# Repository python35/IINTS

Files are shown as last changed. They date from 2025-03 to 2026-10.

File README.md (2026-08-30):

# IINTS MK1

**Original first-generation open-source insulin pump research prototype**

> You are viewing the **`mk1` branch**. For the second-generation firmware,
> Calm Mode, UI simulator, controller PCB, and open KiCad design files, open the
> [`mk2` branch](https://github.com/python35/IINTS/tree/mk2).

<div align="center">
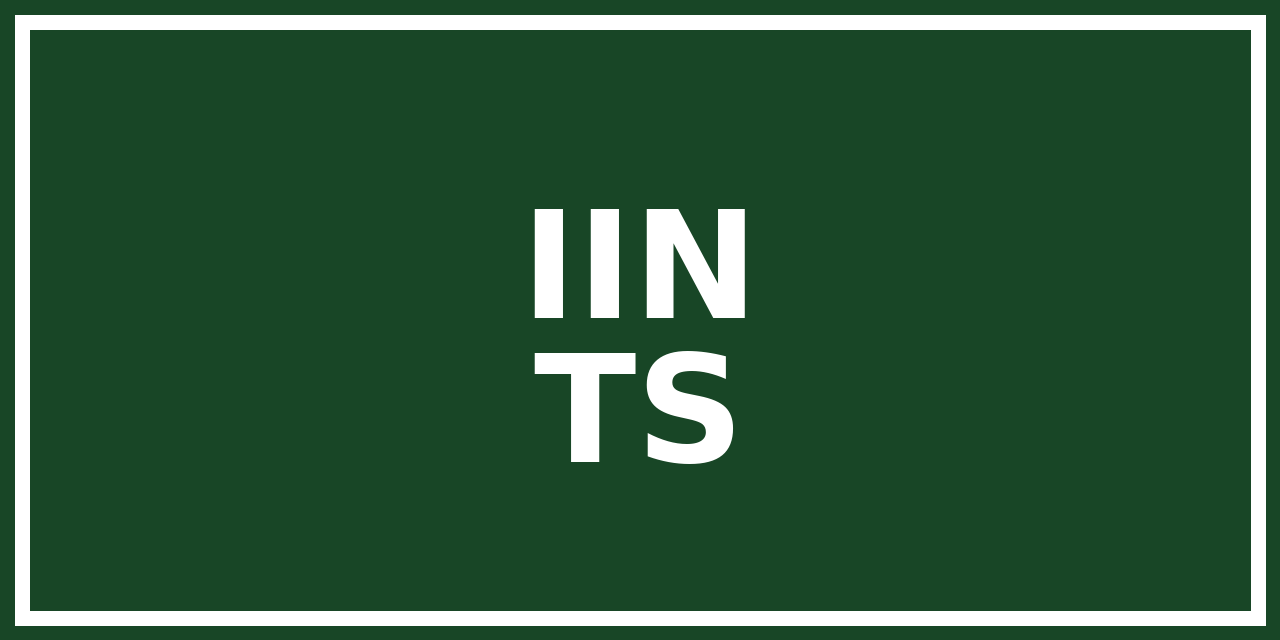
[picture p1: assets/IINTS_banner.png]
  
</div>

**IINTS MK1** (*Insuline Is Not The Solution*) is the original open-source educational insulin pump prototype built around the **Raspberry Pi Pico**.

The project started as an experiment to understand how insulin pumps work from an engineering perspective: how a motor can create precise linear movement, how that movement can be translated into fluid displacement, and how embedded software can control the complete mechanism.

The first generation of IINTS combines a **Raspberry Pi Pico**, a **stepper-driven syringe mechanism**, a display, physical controls, and a 3D-printed enclosure.

> **Important:** IINTS is an educational and research prototype.
> It is **not a medical device**, has not been clinically validated or certified, and must **not be used to administer insulin or any other medication to a person**.

## Project Branches

- **`mk1` branch:** The original pump firmware, assets, guide, and mechanical
  files documented on this page.
- **`mk2` branch:** The second-generation controller, firmware, Calm Mode,
  simulator, PCB sources, and dedicated MK2 documentation are available on
  [the MK2 branch](https://github.com/python35/IINTS/tree/mk2).

---

## About the Project

I started IINTS in **2024** after becoming curious about the technology behind the insulin pumps I had been using for most of my life.

Instead of treating the pump as a closed box, I wanted to understand what was happening inside it:

* How does a pump physically move a small amount of fluid?
* How can a stepper motor be controlled accurately?
* How do mechanical dimensions influence displacement?
* How can an embedded user interface control the mechanism?
* What engineering challenges appear when combining electronics, software and mechanics into a small device?

IINTS became my way of exploring those questions by building a pump mechanism from scratch.

The project is published as open source so that others interested in **embedded systems, electronics, programming, 3D printing and medical technology** can study and experiment with the concepts behind it.

---

## Project History

### Milestones

* **May 2024** – First working prototype using a Raspberry Pi Pico
* **July 2024** – Added a display and user interface
* **December 2024** – Introduced microstepping experiments to improve motor control and mechanical resolution
* **April 2025** – Awarded **Most Technically Complex Project** at Coolest Projects Belgium
* **May 2025** – Named **Student in the Spotlight** for the third time, this time for IINTS
* **July 2025** – Ranked among the top 7% of applicants from more than 120 countries for the CERN Solvay Student Camp
* **August 2025** – Presented IINTS at the CIONET Summer Festival
* **October 2025** – Presented the project at HackYeah in Kraków, Poland

---

## Hardware Overview

The first-generation IINTS prototype consists of several main subsystems:

### Controller

* **Raspberry Pi Pico**
* RP2040 microcontroller
* Firmware written in **MicroPython**

The Pico controls the motor, display and physical user inputs.

### Motor System

A small stepper motor drives a threaded linear mechanism.

Rotational movement from the motor is converted into linear movement, which pushes the syringe plunger forward.

The motor is controlled through a dedicated motor driver.

### User Interface

The prototype includes:

* Display-based interface
* Physical push buttons
* Motor control
* Basic device status information

### Mechanical System

The mechanical assembly consists of:

* Stepper motor
* Threaded spindle / linear actuator
* Syringe holder
* Plunger mechanism
* 3D-printed mounting components
* 3D-printed enclosure

---

## How the Pump Mechanism Works

The basic mechanical principle is relatively simple.

A stepper motor rotates a threaded spindle. The spindle converts the rotational movement of the motor into linear movement.

That linear movement pushes the plunger of a syringe.

Because the dimensions of the syringe, spindle pitch and motor movement are known, the theoretical fluid displacement per motor revolution or motor step can be estimated.

### Volume per Revolution

For a syringe with internal radius \(r\) and a spindle with pitch \(p\):

$$
V_{rev} = \pi r^2 p
$$

where:

* \(V_{rev}\) = theoretical displaced volume per spindle revolution
* \(r\) = internal radius of the syringe
* \(p\) = linear spindle travel per revolution

### Volume per Motor Step

If the motor requires \(N_{steps}\) controlled steps for one revolution:

$$
V_{step} = \frac{V_{rev}}{N_{steps}}
$$

This provides a theoretical relationship between motor movement and syringe displacement.

These equations describe the **mechanical principle only**. Real systems are affected by factors such as backlash, friction, syringe tolerances, motor accuracy, compliance and assembly tolerances.

The calculations in this repository must therefore **not be interpreted as validated medication-delivery accuracy**.

---

## Features

### Raspberry Pi Pico Control

The device is controlled by an RP2040-based Raspberry Pi Pico running MicroPython.

### Stepper Motor Control

A stepper motor provides controlled mechanical movement of the syringe plunger.

### Display Interface

A small display provides a graphical interface for interacting with the prototype.

### Physical Controls

Push buttons allow the user to navigate the interface and control the demonstrator.

### 3D-Printed Mechanism

The enclosure and several mechanical components can be produced using a standard FDM 3D printer.

### Open Source

The firmware, mechanical designs and documentation are publicly available so that the project can be studied, modified and improved.

---

## Project Images

<table align="center">
  <tr>
    <td align="center">
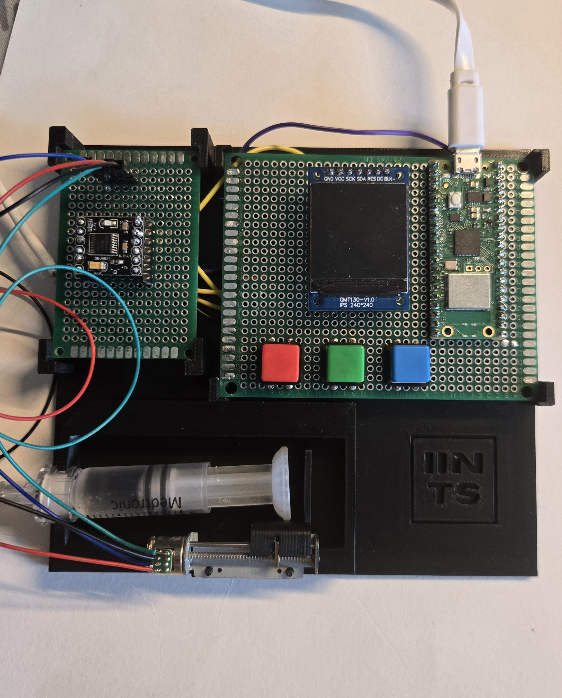
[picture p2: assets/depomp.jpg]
      
    </td>
  </tr>
  <tr>
    <td align="center">
      First-generation IINTS prototype
    </td>
  </tr>
</table>

---

## Hardware

The exact hardware used has changed during development, but the prototype is built around the following components.

### Electronics

* **Raspberry Pi Pico (RP2040)**
* **TFT / graphical display**
* **Stepper motor**
* **Stepper motor driver**
* **Physical push buttons**
* **USB or battery-based power supply**

### Mechanical Components

* Syringe-based linear mechanism
* Threaded spindle / actuator
* Motor mount
* Syringe mount
* Plunger interface
* 3D-printed enclosure

> Different revisions of the prototype may use different components or wiring.
> Check the firmware and hardware files in the repository for the configuration corresponding to a specific revision.

---

## 3D Printing

The available 3D-printable components can be found in the [`/stl`](https://github.com/python35/IINTS/tree/mk1/stl) directory.

### Suggested Starting Settings

These settings were used as a general starting point during prototyping:

* **Material:** PLA or PETG
* **Layer height:** 0.2 mm
* **Infill:** approximately 20%
* **Bed adhesion:** skirt or brim where necessary
* **Supports:** dependent on part orientation

These are prototype settings rather than strict manufacturing specifications.

---

## 3D Printing Timelapses

3D Print Timelapse 1

3D Print Timelapse 2

---

## Software

The firmware is written in **MicroPython** and runs directly on the Raspberry Pi Pico.

### MicroPython Version

The original prototype was developed using:

**MicroPython v1.23.0 – 2024-06-02**

for the Raspberry Pi Pico.

MicroPython firmware for the Raspberry Pi Pico is available at:

https://micropython.org/download/RPI_PICO/

### Check the Installed Version

Connect to the MicroPython REPL and run:

```python
import os
print(os.uname())
```

---

## Development Environment

The original firmware was primarily developed using **Thonny**.

Thonny can be downloaded from:

https://thonny.org/

### Raspberry Pi Pico Setup

1. Connect the Raspberry Pi Pico to your computer.
2. Open Thonny.
3. Select the Raspberry Pi Pico / MicroPython interpreter.
4. Install MicroPython on the Pico if necessary.
5. Copy the required project files to the Pico.
6. Run the firmware.

---

## Clone the Repository

```bash
git clone https://github.com/python35/IINTS.git
cd IINTS
```

You can also download the repository as a ZIP file directly from GitHub.

---

## Repository Structure

The repository contains the different parts of the first-generation IINTS project, including firmware, assets and mechanical files.

For example:

```text
IINTS/
├── assets/
│   └── project images and media
│
├── stl/
│   └── 3D-printable components
│
├── main.py
│   └── main MicroPython firmware
│
└── README.md
```

The exact structure may change as the repository evolves.

---

## What This Project Is

IINTS is intended as:

* an educational embedded-systems project
* an exploration of insulin-pump mechanics
* an open-source hardware experiment
* a way to study stepper motor control
* a project for learning MicroPython
* an example of combining electronics, software and 3D printing
* a platform for discussing transparency in medical technology

---

## What This Project Is Not

IINTS is **not**:

* a certified insulin pump
* a replacement for a commercial insulin pump
* clinically validated
* intended for treatment decisions
* intended for administering medication
* a source of medical dosing advice
* suitable for human use

The project demonstrates engineering concepts only.

---

## Contributing

Contributions are welcome.

If you want to experiment with the project:

1. Fork the repository.
2. Create your own branch.
3. Make and document your changes.
4. Submit a Pull Request.

Improvements to the firmware, documentation, electronics, mechanical design and simulation tools are all welcome.

Please keep the educational and non-clinical nature of the project clear when contributing.

---

## License

This repository is licensed under the **MIT License**.

The license allows the source code and project files to be used, modified and redistributed under the terms of the MIT License.

The MIT License does **not** imply that the hardware or software is safe, clinically validated, medically approved or suitable for use as a medical device.

---

## Safety Disclaimer

**IINTS is an experimental educational prototype.**

The hardware, firmware, mechanical components and calculations in this repository have **not been designed, tested, validated or certified for clinical use**.

Do not connect this prototype to a person and do not use it to administer insulin, medication or other substances.

Commercial insulin pumps are safety-critical medical devices that require extensive engineering controls, verification, validation, risk management, manufacturing controls and regulatory approval. This project does not provide those guarantees.

Use the repository only for **education, research and engineering experimentation**.

---

## Special Thanks

A special thank you to the **coaches of CoderDojo Genk and Hasselt** for their guidance and support throughout the development of IINTS.

Their feedback and mentorship helped turn an early experiment into a much larger engineering and educational project.

---

## Related Development

This repository documents the **original hardware-focused generation of IINTS**.

The project has since grown beyond the physical pump prototype into broader research and educational work around diabetes technology, simulation, algorithmic safety and transparent medical technology.

The original pump remains an important part of that story: it was the starting point for understanding what happens between a line of software and the physical movement of a medical device.

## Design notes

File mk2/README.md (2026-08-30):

# IINTS MK2

**Neuro-inclusive insulin pump simulator, open hardware study, and
electromechanical demonstrator**

[Back to the main IINTS repository](../README.md)

This README describes the **IINTS MK2 only**. The MK1 has different hardware,
wiring, firmware, and interaction patterns.

> [!CAUTION]
> **Research and education prototype only.** IINTS MK2 is not a certified
> medical device and must not be used to make treatment decisions or deliver
> insulin to a person. Test the mechanism disconnected from a person and use
> water or another harmless test liquid. The calculations and safety checks are
> demonstrations, not a substitute for validated pump firmware or clinical
> supervision.

<table>
  <tr>
    <td width="50%" align="center">
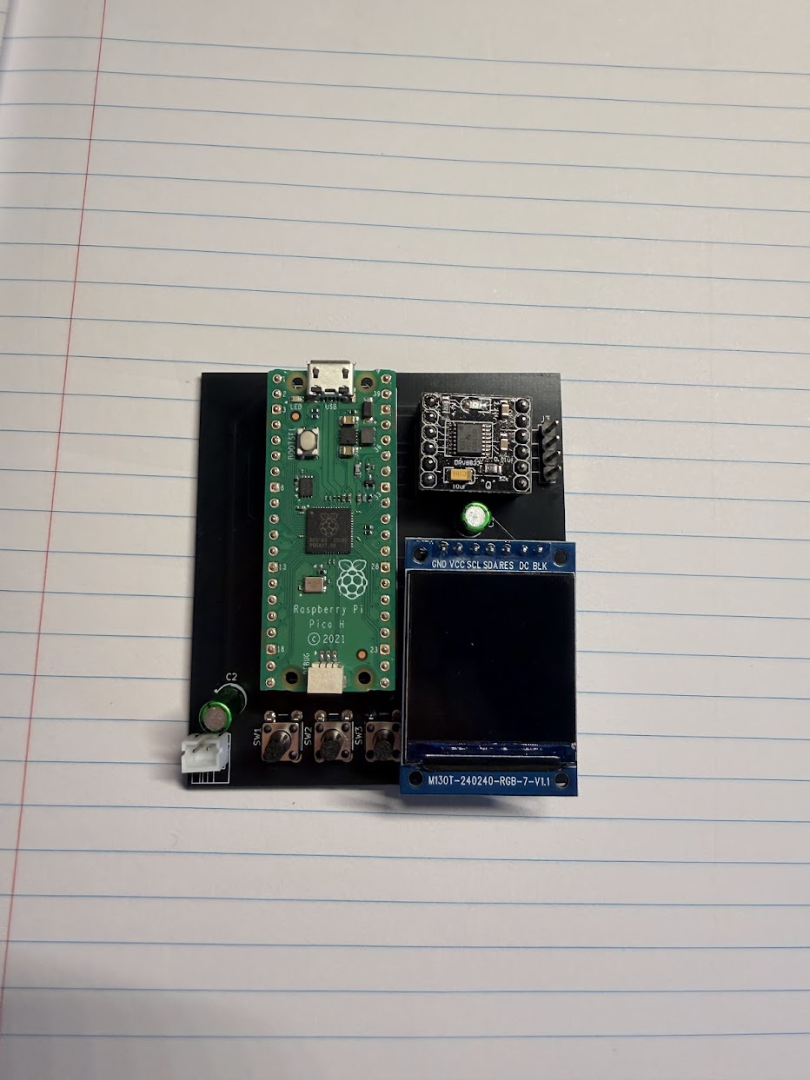
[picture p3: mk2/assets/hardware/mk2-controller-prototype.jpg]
Photograph of the IINTS MK2 controller PCB
      
    </td>
    <td width="50%" align="center">
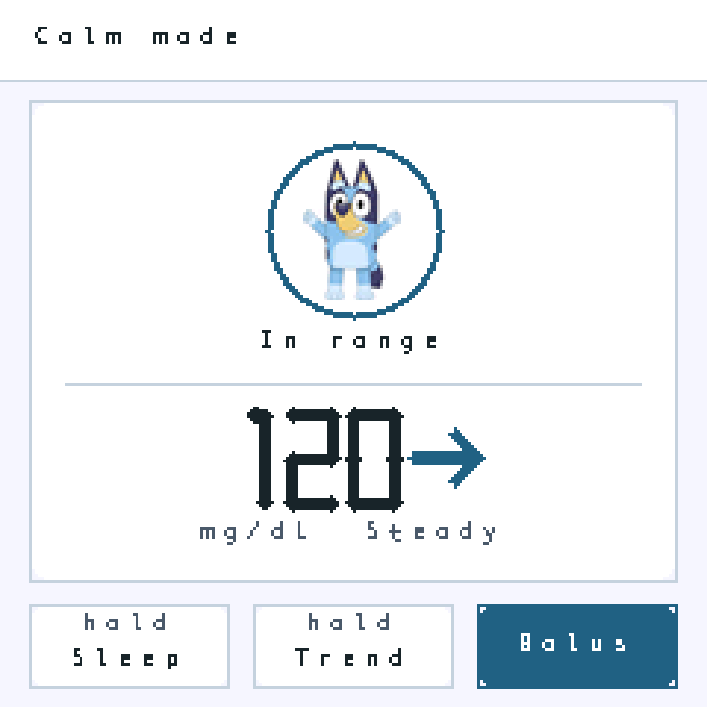
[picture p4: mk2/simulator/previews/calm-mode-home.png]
IINTS MK2 Calm Mode home screen
      
    </td>
  </tr>
  <tr>
    <td align="center"><strong>MK2 controller prototype</strong></td>
    <td align="center"><strong>Calm Mode interface</strong></td>
  </tr>
</table>

## Quick Links

| Area | Open files |
| --- | --- |
| Firmware source | [`firmware/pico_drv8833_correct_pins.py`](firmware/pico_drv8833_correct_pins.py) |
| Ready-to-upload Pico build | [`firmware/deploy/`](firmware/deploy/) |
| PCB V2 KiCad project | [`hardware/pcb-v2/`](hardware/pcb-v2/) |
| Desktop UI simulator | [`simulator/`](simulator/) |
| Complete UI overview | [`simulator/previews/current-ui-overview.png`](simulator/previews/current-ui-overview.png) |
| Calm Mode documentation | [`docs/NEURODIVERGENT_MODE.md`](docs/NEURODIVERGENT_MODE.md) |
| Simulator guide | [`docs/UI_SIMULATOR.md`](docs/UI_SIMULATOR.md) |
| MK2 project report | [`docs/IINTS-MK2.pdf`](docs/IINTS-MK2.pdf) |

## Overview

IINTS MK2 combines a Raspberry Pi Pico, a custom controller PCB/prototype
board, a 240 x 240 ST7789 IPS display, three physical buttons, a DRV8833 motor
driver, and a bipolar stepper motor. The prototype demonstrates:

- a virtual CGM value in `mg/dL`, refreshed once per minute;
- a visible rising, steady, or falling trend;
- standard and low-sensory **Calm Mode** interfaces;
- a guided carbohydrate and bolus flow;
- a separate adult confirmation before motor movement;
- educational IOB, COB, correction, and meal-dose calculations;
- a delivery animation and flashing onboard LED while the motor runs;
- glucose history, settings, manual rewind, screen locking, and power saving;
- a desktop simulator that previews the real firmware drawing functions;
- open MicroPython firmware, deployment files, documentation, assets, and
  editable KiCad design source.

The current firmware interface is in English.

## What Is New In MK2

Compared with the original concept, MK2 is built around a complete three-button
workflow and a full-colour IPS interface. Its main additions are the virtual CGM,
trend history, Calm Mode, visual meal portions, adult hand-off, runtime settings,
manual rewind, delivery feedback, and automatic sleep.

The desktop UI simulator is part of the MK2 workflow. It allows the 240 x 240
screens to be reviewed before anything is uploaded to the Pico.

## Project Status

| Part | Status |
| --- | --- |
| MicroPython firmware source | Published and used by the current prototype |
| Compiled Pico deployment package | Published in `firmware/deploy/` |
| Desktop UI simulator | Published and usable without a Pico |
| Calm Mode and buddy assets | Published with a separate artwork notice |
| MK2 controller photograph | Published in `assets/hardware/` |
| KiCad schematic source | Published as an editable V2 design draft |
| KiCad PCB layout | Early placeholder; not fabrication-ready |
| Gerbers, drill files, BOM, pick-and-place | Not released because the PCB design is unfinished |
| Medical or clinical validation | Not performed |

Publishing a source file does not make it a finished manufacturing release.
The exact PCB status is documented in the
[PCB V2 design notes](hardware/pcb-v2/README.md).

## User Interface

### Standard mode

Standard mode keeps the clinical data visible. The home screen shows the current
virtual sensor value, its direction, IOB, and COB. The bolus flow then asks for
carbohydrates, shows the calculated dose, and requires confirmation before the
motor can start.

### Calm Mode

Calm Mode reduces the number of decisions and visual elements shown at once:

- one primary task per screen;
- a fixed header, content area, and three-button footer;
- a cool-white background, dark text, and one muted-blue focus colour;
- written status labels in addition to colour and symbols;
- a small buddy image that supports, but never replaces, the glucose value;
- five predictable meal portions: `0`, `15`, `30`, `45`, and `60 g`;
- a dedicated Adult Check with a deliberate `1.4 s` hold;
- Calm Pause, which stops motor output and shows three short steps.

The UI is intended to reduce sensory and cognitive load. It has not undergone a
formal accessibility or medical usability certification.

<details>
<summary><strong>View the complete current 240 x 240 UI overview</strong></summary>

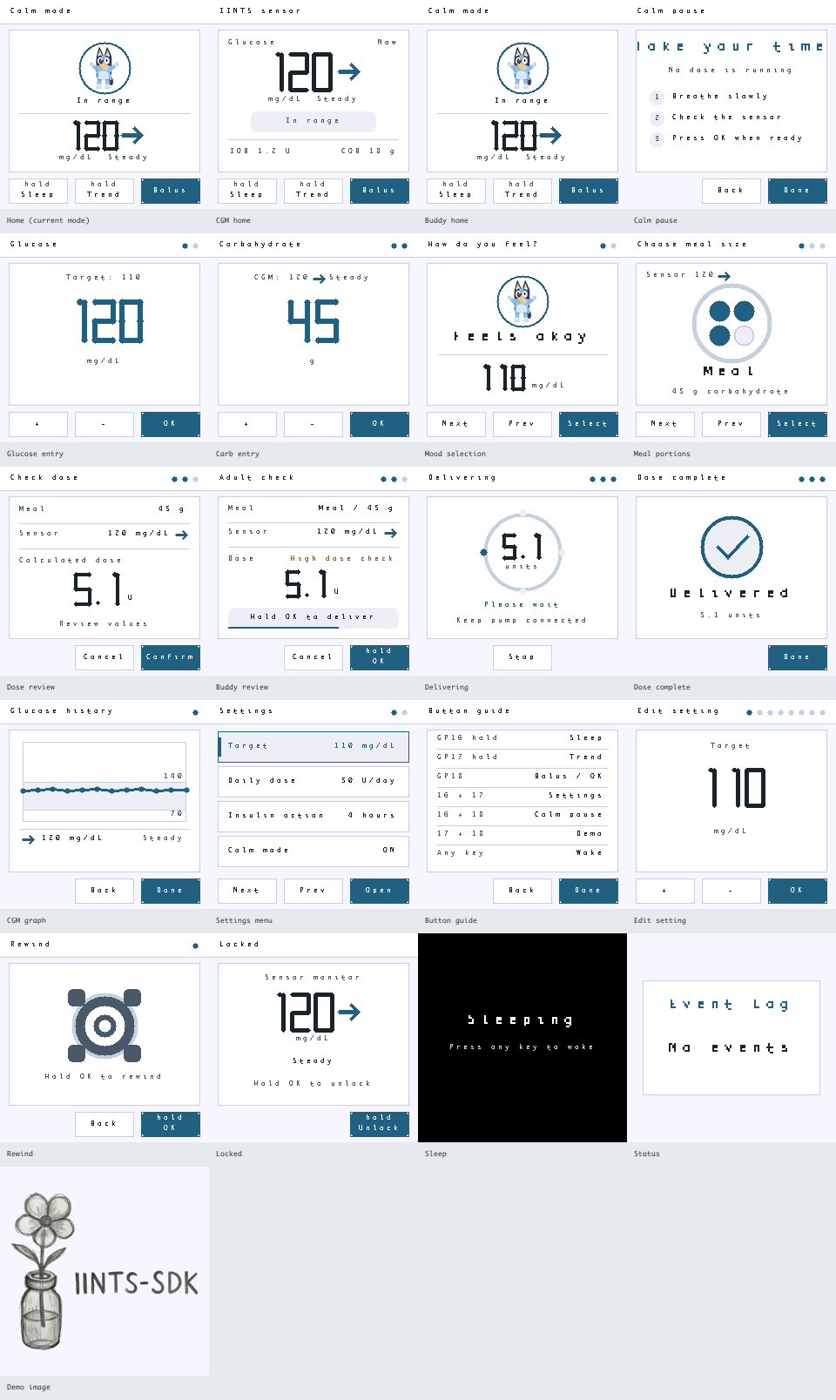
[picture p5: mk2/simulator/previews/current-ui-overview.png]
Complete IINTS MK2 interface overview


</details>

## Hardware

| Component | MK2 role |
| --- | --- |
| Raspberry Pi Pico or Pico W | Runs MicroPython, calculations, UI, and motor state machine |
| 240 x 240 ST7789 IPS display | Main interface over SPI1 |
| DRV8833 dual H-bridge | Drives the bipolar stepper motor |
| Bipolar stepper motor | Demonstrates plunger movement |
| Lead screw and test reservoir | Converts rotation into linear movement |
| Three active-low push buttons | Previous/down, next/up, and OK |
| External motor battery/supply | Powers `VM` on the motor driver |

The motor calculation currently assumes a 200-step motor, a `0.5 mm` lead-screw
pitch, and a `9.5 mm` reservoir inner diameter. Real hardware must be measured
and calibrated before its movement can be interpreted as a volume.

## Open PCB V2 Design

The complete supplied KiCad V2 source is available in
[`hardware/pcb-v2/`](hardware/pcb-v2/). Open
[`ai_pomp.kicad_pro`](hardware/pcb-v2/ai_pomp.kicad_pro) with **KiCad 9**.

The directory includes the project, root schematic, hierarchical schematic
sheets for USB-C, the display, controller pins, motor driver, and buttons, plus
the early PCB placement file. Temporary locks, autosaves, and backup archives
are deliberately excluded because Git provides the version history.

> [!WARNING]
> The supplied KiCad files are an early V2 design study. The PCB file still
> contains generic placeholder footprints and is not routed or ready to order.
> It does not yet match the photographed Pico-based controller one-to-one. Read
> the [PCB design notes](hardware/pcb-v2/README.md) before reusing it.

This distinction keeps the full design history public without presenting an
unfinished board as validated hardware.

## Wiring

The GPIO names below are the source of truth for the firmware. Physical pin
numbers refer to a standard 40-pin Raspberry Pi Pico/Pico W.

### Pico to DRV8833

| Pico GPIO | Physical pin | DRV8833 |
| --- | ---: | --- |
| `GP4` | 6 | `IN1` |
| `GP5` | 7 | `IN2` |
| `GP6` | 9 | `IN3` |
| `GP9` | 12 | `IN4` |
| `GP28` | 34 | `EEP` / enable |
| `3V3(OUT)` | 36 | Logic `VCC`, if present on the module |
| `GND` | 38 | `GND` |

### DRV8833 to motor

| DRV8833 | Motor |
| --- | --- |
| `OUT1` | Coil A+ |
| `OUT2` | Coil A- |
| `OUT3` | Coil B+ |
| `OUT4` | Coil B- |

If the motor only vibrates, verify the two coil pairs before changing the
firmware sequence.

### Display to Pico

| Display | Pico GPIO | Physical pin |
| --- | --- | ---: |
| `GND` | `GND` | Any Pico GND |
| `VCC` | `3V3(OUT)` | 36 |
| `SCK` | `GP10` | 14 |
| `SDA` / `MOSI` | `GP11` | 15 |
| `RES` | `GP12` | 16 |
| `DC` | `GP13` | 17 |
| `BLK` | `3V3(OUT)` | 36 |

`BLK` is connected directly to 3.3 V, so the current firmware cannot dim the
backlight with PWM.

### Buttons

| Button | Pico GPIO | Physical pin | Other side |
| --- | --- | ---: | --- |
| Button 1 | `GP16` | 21 | `GND` |
| Button 2 | `GP17` | 22 | `GND` |
| Button 3 | `GP18` | 24 | `GND` |

The firmware enables the Pico's internal pull-up resistors. A pressed button
therefore reads `LOW`.

### Power

- Battery positive goes to DRV8833 `VM`.
- Battery negative goes to the common ground.
- Pico GND, DRV8833 GND, battery negative, display GND, and button GND must be
  connected together.
- Do not power the motor from the Pico's 3.3 V output.
- On a standard Pico, physical pin **36** is `3V3(OUT)`. Physical pin **40** is
  `VBUS`, not 3.3 V. Verify the exact board and driver-module pinout before
  applying power.

See the [official Raspberry Pi Pico documentation](https://www.raspberrypi.com/documentation/microcontrollers/pico-series.html)
for the board pinout.

## Complete Control Legend

| Input | Normal action |
| --- | --- |
| `GP16` | Next, increase, or move upward |
| `GP17` | Previous, decrease, back, cancel, or stop delivery |
| `GP18` | Select, OK, confirm, or continue |

Values repeat automatically while `GP16` or `GP17` is held. Repeating becomes
faster after approximately `0.9 s` and faster again after `2.2 s`.

| Hold or combination | Action |
| --- | --- |
| Hold `GP16` for `2.5 s` on Home | Enter power-saving sleep |
| Hold `GP17` for `0.9 s` on Home | Open glucose history |
| Hold `GP18` during Adult Check | Confirm delivery after `1.4 s` |
| Hold `GP18` in Rewind | Run the motor backwards only while held |
| Hold `GP16 + GP17` for `0.7 s` | Open or close Settings |
| Hold `GP16 + GP18` for `0.7 s` in Calm Mode | Open Calm Pause |
| Hold `GP17 + GP18` for `0.7 s` | Show or close the project image/demo |
| Press any button while sleeping | Wake the display and driver |

The same legend is available on the device under `Settings > Button guide`.

## Guided Bolus Flow

With the default virtual CGM and Calm Mode enabled:

1. Home shows the current sensor value and trend.
2. Press `GP18` to start a bolus.
3. Select one of the five meal portions.
4. Review the meal, sensor value, trend, and calculated dose.
5. Continue to Adult Check.
6. An adult holds `GP18` for `1.4 s` to authorize motor movement.
7. During delivery, an hourglass-style animation is shown and the onboard Pico
   LED flashes.
8. Press `GP17` to stop delivery early.
9. A quiet checkmark confirms completion.

In Standard mode, carbohydrates can be changed in grams. Holding a value button
accelerates the adjustment.

## Settings

Open Settings by holding `GP16 + GP17` for `0.7 s`.

| Setting | Default | Range or action |
| --- | ---: | --- |
| Target | `110 mg/dL` | `80-180 mg/dL` |
| Daily dose (TDD) | `50 U/day` | `10-100 U/day` |
| Insulin action (DIA) | `4 h` | `2-8 h` |
| Calm Mode | On | On/off |
| CGM sensor simulation | On | On/off |
| Animations | On | On/off |
| Rewind | - | Hold `GP18` to reverse motor movement |
| Button guide | - | Opens the complete onboard legend |

Settings currently live in RAM only. Restarting the Pico restores the defaults
defined in `pico_drv8833_correct_pins.py`.

## Active Educational Model

The following calculations are active in the current bolus path.

### Patient factors

Using total daily dose `TDD`:

```text
ICR = 500 / TDD       grams per unit
ISF = 1800 / TDD      mg/dL per unit
```

At the default `TDD = 50 U/day`, this gives `ICR = 10 g/U` and
`ISF = 36 mg/dL/U`.

### Insulin on board

For each logged dose still inside the configured duration of insulin action:

```text
remaining IOB = dose * (1 - elapsed / DIA)^2
```

This is a simplified quadratic demonstration model. It must not be presented as
a validated patient-specific pharmacokinetic model.

### Carbohydrates on board

COB decreases linearly over `3 h` for standard portions and `6 h` for the
largest meal portion.

### Bolus calculation

```text
meal dose       = carbohydrates / ICR
correction dose = (current BG - target BG) / ISF
protected IOB   = max(0, IOB - COB / ICR)
bolus           = max(0, meal dose + correction dose - protected IOB)
```

The result is then limited by the educational guardrails below.

### Motor conversion

The current assumptions are:

```text
reservoir radius       = 4.75 mm
lead-screw pitch       = 0.5 mm/revolution
stepper resolution     = 200 steps/revolution
U-100 reference volume = 10 microlitres/unit
calculated output      = 3.544 units/revolution
calculated resolution  = 56.43 steps/unit
```

These values describe the software model, not a calibration certificate for the
physical prototype.

## Educational Guardrails

| Check | Current behaviour |
| --- | --- |
| Low-glucose lockout | A calculated bolus is blocked at or below `70 mg/dL` |
| Single-bolus limit | Requested dose is clamped to `15.0 U` |
| Rolling dose limit | Logged delivery since boot is limited to `2 x TDD` over 24 hours |
| Adult hand-off | Calm Mode requires a continuous `1.4 s` hold before delivery |
| Delivery cancel | `GP17` stops the motor and records only completed steps |
| Motor shutdown | All four driver inputs are set low after movement |

These safeguards are implemented for demonstration and have not been validated
to medical-device standards. The injection and carbohydrate logs are volatile;
they are lost when power is removed.

The source also contains experimental PID basal, predictive-low-glucose, and
sensor-noise helper functions. They are **not connected to the current main
delivery loop** and should not be described as active closed-loop control.

## Virtual CGM

The MK2 does not currently communicate with a physical glucose sensor. The
default demo cycles through this sequence once per minute:

```text
118, 124, 132, 145, 158, 151, 138, 126, 113, 101, 108, 116 mg/dL
```

The trend is rising for a change of at least `+5 mg/dL`, falling for a change of
at most `-5 mg/dL`, and steady otherwise. Up to 24 samples are kept in RAM for
the history graph.

## Locking And Power Saving

- Home locks after `30 s` without input while the virtual CGM is active.
- The display and driver enter sleep after `180 s` without input.
- Holding `GP16` for `2.5 s` enters sleep immediately.
- Sleep disables the motor, turns off the delivery LED, lowers the driver enable
  pin, sends the ST7789 sleep command, and uses Pico light sleep where available.
- Any button wakes the prototype.

Because `BLK` is wired directly to 3.3 V, actual backlight power depends on the
display module. For maximum battery saving, route `BLK` through a suitable GPIO
or transistor in a future hardware revision.

## Repository Layout

```text
mk2/
|-- README.md                         # This GitHub start page
|-- assets/
|   |-- branding/                     # IINTS logo and startup preview
|   |-- bluey/                        # Source, generated assets, and rights note
|   `-- hardware/                     # MK2 controller photograph
|-- docs/                             # Project report and focused guides
|-- firmware/
|   |-- pico_drv8833_correct_pins.py  # Canonical readable firmware
|   |-- st7789.py                     # Display driver
|   `-- deploy/                       # Ready-to-copy Pico filesystem
|-- hardware/
|   `-- pcb-v2/                       # Editable KiCad 9 V2 design source
|-- simulator/                        # Safe desktop UI simulator and previews
|-- tools/                            # Asset preparation and button tests
`-- requirements.txt                  # Desktop development dependencies
```

Only `happy_calm.raw`, `sad_calm.raw`, and `angry_calm.raw` are used by the
current buddy interface. Old food-image and startup-video experiments are not
part of the deployed MK2 package.

## Preview The UI

The simulator needs Python 3 and Tkinter, but no connected Pico:

```bash
cd mk2
python3 -m venv .venv
source .venv/bin/activate
python -m pip install -r requirements.txt
python simulator/ui_simulator.py
```

On macOS, double-click `simulator/Open UI Simulator.command`. The simulator can
preview individual screens, emulate all three buttons, auto-reload UI changes,
save screenshots, and export a complete contact sheet.

Generate a contact sheet from the command line with:

```bash
python simulator/ui_simulator.py \
  --contact-sheet simulator/previews/all-screens.png
```

The simulator replaces GPIO, SPI, timing, and motor access with desktop stubs.
It validates layout and interaction screens, not physical delivery behaviour.

See the [simulator guide](docs/UI_SIMULATOR.md) for the full workflow.

## Build The Pico Application

Install a current MicroPython build for the exact Pico model and confirm that a
REPL is available. Then create the development environment:

```bash
cd mk2
python3 -m venv .venv
source .venv/bin/activate
python -m pip install -r requirements.txt
```

Compile the large source file before copying it to the Pico:

```bash
mpy-cross \
  -o firmware/deploy/pico_app.mpy \
  firmware/pico_drv8833_correct_pins.py
```

The `mpy-cross` format must be compatible with the MicroPython firmware on the
Pico. An incompatible build raises `ValueError: incompatible .mpy file`. See
the [official MicroPython `.mpy` documentation](https://docs.micropython.org/en/latest/reference/mpyfiles.html).

The included deploy build is documented as tested with MicroPython 1.28.0.
Rebuild it whenever the Pico firmware or readable source changes.

## Deploy To A Pico

Back up the Pico filesystem first. The ready-to-copy directory contains:

```text
firmware/deploy/
|-- main.py
|-- pico_app.mpy
|-- st7789.py
|-- start.raw
|-- happy_calm.raw
|-- sad_calm.raw
`-- angry_calm.raw
```

With the development environment active and the Pico connected:

```bash
mpremote connect auto fs cp \
  firmware/deploy/main.py \
  firmware/deploy/pico_app.mpy \
  firmware/deploy/st7789.py \
  firmware/deploy/start.raw \
  firmware/deploy/happy_calm.raw \
  firmware/deploy/sad_calm.raw \
  firmware/deploy/angry_calm.raw :

mpremote connect auto reset
```

The deployment `main.py` imports only `pico_app.mpy`. This avoids compiling the
large readable firmware source on the Pico and reduces the chance of
`MemoryError`. The explanatory `firmware/deploy/README.md` is not needed on the
device.

The same files can be uploaded with Thonny. Place all seven runtime files in the
Pico filesystem root and restart the board.

## Troubleshooting

### `ImportError: no module named 'st7789'`

Upload `firmware/deploy/st7789.py` to the Pico root next to `pico_app.mpy`.

### `MemoryError`

- Use `firmware/deploy/pico_app.mpy` with the minimal deployment `main.py`.
- Remove the large `.py` application source from the Pico after compiling it.
- Remove obsolete video frames, food photos, and unused raw assets.
- Keep the three 64 x 64 buddy files streamed from flash; do not load a full
  image into RAM.

### `ValueError: incompatible .mpy file`

Recompile with an `mpy-cross` release that matches the MicroPython firmware on
the Pico.

### Buttons do not respond

- Confirm that each button connects its GPIO to common GND when pressed.
- Run `tools/test_buttons.py` or `tools/scan_buttons_safe.py` first.
- Check `GP16`, `GP17`, and `GP18`; the inputs are active low.
- Release all buttons before testing a two-button hold.

### The motor vibrates but does not rotate

Identify the two motor coils with a multimeter and connect each complete coil to
one DRV8833 output pair. Also verify `VM`, common ground, and `GP28` enable.

### Buddy images are missing

The UI falls back to a geometric face if an image cannot be opened. Confirm the
exact filenames in the Pico filesystem root:

```text
happy_calm.raw
sad_calm.raw
angry_calm.raw
```

## Suggested Test Order

1. Review every screen in `simulator/ui_simulator.py`.
2. Test the three buttons with the motor supply disconnected.
3. Confirm display colours, labels, sleep, wake, Settings, and button combos.
4. Test motor direction without a reservoir attached.
5. Calibrate mechanical travel with a ruler or dial indicator.
6. Test repeatability with water and a precision scale.
7. Record the firmware version, measured geometry, supply voltage, and results.

Do not proceed from bench testing to human use. A real insulin pump requires a
validated risk-management process, redundant fault detection, verified dosing,
biocompatible fluid paths, alarms, persistent records, cybersecurity controls,
and regulatory approval that this prototype does not provide.

## Current Limitations

- virtual CGM only; no Bluetooth or physical sensor connection;
- no active basal-delivery schedule or validated closed-loop controller;
- no non-volatile settings, dose history, or event log;
- no occlusion, reservoir, battery-voltage, current, or motor-position sensor;
- no redundant processor or independent motor cutoff;
- unfinished PCB V2 design with no released manufacturing package;
- no MK2-specific enclosure CAD in this directory;
- no formal IEC 62304, ISO 14971, IEC 62366, electrical-safety, or clinical
  validation.

These limitations are intentionally explicit so the MK2 can be presented
accurately as a research demonstrator.

## License And Artwork

The original source code, KiCad files, and project documentation are published
under the repository's [MIT License](../LICENSE).

The optional Bluey buddy artwork is third-party material and is **not** covered
by the MIT License. All rights to that artwork remain with the relevant rights
holders. IINTS is not affiliated with or endorsed by them. See the
[Bluey asset notice](assets/bluey/README.md) for details.

## Author

Developed by **Rune Bobbaers** as part of the **IINTS** research project.

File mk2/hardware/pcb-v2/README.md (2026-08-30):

# IINTS MK2 PCB V2

This directory contains the editable KiCad source files supplied for the IINTS
V2 electronics concept. Open `ai_pomp.kicad_pro` with **KiCad 9** to inspect or
continue the design.

> [!WARNING]
> **Design source, not a production release.** The current board file is an
> early placement placeholder. It has no finished board outline, routing,
> copper pours, verified netlist, fabrication outputs, or manufacturing
> validation. Do not order this board or connect it to a person on the basis of
> these files.

## Project Files

| File | Purpose |
| --- | --- |
| `ai_pomp.kicad_pro` | Main KiCad project settings |
| `ai_pomp.kicad_sch` | Root hierarchical schematic |
| `ai_pomp.kicad_pcb` | Early PCB placement concept |
| `USB-C.kicad_sch` | USB-C power-input draft |
| `untitled.kicad_sch` | Seven-pin display connector sheet |
| `Motor_Driver.kicad_sch` | Motor-driver draft sheet |
| `Pinnen.kicad_sch` | Controller-pin/header draft sheet |
| `Schermpje.kicad_sch` | Additional interface draft sheet |
| `1e-knopje.kicad_sch` | Button 1 draft |
| `2e-knopje.kicad_sch` | Button 2 draft |
| `3e-knopje.kicad_sch` | Button 3 draft |

KiCad lock files, personal preferences, autosaves, and backup archives are
deliberately excluded. Git already provides version history for the published
source files.

## Known Differences From The Current MK2 Prototype

The active MK2 firmware and photographed controller use a Raspberry Pi Pico,
three buttons, a DRV8833 module, and a 240 x 240 ST7789 display. The supplied
KiCad draft predates that final wiring choice:

- `Pinnen.kicad_sch` describes a generic 2 x 20 controller header rather than
  the Pico's 40 castellated pins;
- `ai_pomp.kicad_pcb` contains placeholder footprints, including a compute
  module and a generic SPI display;
- the PCB file does not yet contain a complete schematic-derived netlist,
  tracks, vias, mounting holes, or a closed `Edge.Cuts` outline;
- the three separate button sheets are retained as source material but are not
  all linked into the current root hierarchy.

The files are published so the design history is open and can be improved, not
to suggest that this revision is fabrication-ready.

## Firmware GPIO Target

A future PCB revision should be checked against the canonical firmware mapping:

| Function | Pico GPIO |
| --- | --- |
| DRV8833 IN1, IN2, IN3, IN4 | `GP4`, `GP5`, `GP6`, `GP9` |
| DRV8833 enable | `GP28` |
| ST7789 SCK, MOSI, RES, DC | `GP10`, `GP11`, `GP12`, `GP13` |
| Buttons 1, 2, 3 | `GP16`, `GP17`, `GP18` to GND |

See the parent [MK2 README](../../README.md) for the complete wiring and power
notes.

## Before Fabrication

At minimum, a new hardware revision needs:

1. Pico/Pico W symbols and footprints that match the chosen board revision.
2. A complete schematic-to-PCB netlist matching the firmware GPIO table.
3. Verified USB-C power circuitry, supply limits, grounding, decoupling, motor
   current, reverse-polarity protection, and battery protection.
4. A finished board outline, mounting holes, connector clearances, routed
   copper, power planes, and readable silkscreen.
5. Clean KiCad ERC and DRC reports reviewed by a qualified electronics engineer.
6. Bench validation with current-limited power and the motor/load disconnected.
7. Gerber, drill, BOM, and pick-and-place exports generated only from the
   reviewed release commit.

This remains an educational electronics prototype and is not a medical-device
hardware design.

## License

These design sources are distributed with the repository under the terms in
the root [`LICENSE`](../../../LICENSE). Third-party symbols, footprints, and
component documentation retain their own applicable terms.

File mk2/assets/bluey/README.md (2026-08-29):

# Bluey Assets

These images are retained as part of the MK.2 Calm Mode prototype at the
project author's request. The `source` directory contains the supplied images;
the `generated` directory contains the 64x64 RGB565 versions used by the Pico.

Bluey is a third-party character. These character images are not covered by
the repository's MIT license, and all rights remain with their respective
rights holders. This research project is not affiliated with or endorsed by
those rights holders.

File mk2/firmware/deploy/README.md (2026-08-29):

# Pico Deploy Folder

Copy the runtime files in this directory to the root of the Pico filesystem;
this `README.md` itself is not required there. The included `pico_app.mpy` was
compiled from `../pico_drv8833_correct_pins.py` and tested with MicroPython
1.28.0.

Do not test motor delivery with insulin connected. This build is a research
prototype and has not been clinically validated.

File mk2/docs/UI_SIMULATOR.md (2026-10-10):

# IINTS UI Simulator

The simulator previews the real drawing functions from
`../firmware/pico_drv8833_correct_pins.py` without connecting to the Pico.

## Requirements

- **Windows**: Python 3.10+ (Tkinter is included with standard Python installations) and Pillow (`pip install pillow`).
- **Linux / WSL (Ubuntu/Debian)**: Tkinter is packaged separately and must be installed via `apt`:
  ```bash
  sudo apt update
  sudo apt install -y python3-tk python3-pil python3-pil.imagetk
  ```
  *(Note: Running GUI applications inside WSL also requires WSLg or an active X11 server).*

## Start

Double-click `simulator/Open UI Simulator.command`, or run:

```bash
cd mk2/simulator
python3 ui_simulator.py
```

On Windows (Command Prompt / PowerShell):

```powershell
cd mk2\simulator
python ui_simulator.py
```

## Workflow

1. Select a screen in the left column.
2. Change glucose, trend, carbs, dose, portion, or mode on the right.
3. Use the GP16, GP17, and GP18 buttons below the display, or keys `1`, `2`, `3`.
4. Use Quick access for Settings, Calm Pause, Trend, and the demo image.
5. Keep Auto-reload enabled while editing the firmware source.
6. Use Screenshot for the current 240x240 screen or Export all for a contact sheet.
7. Open **UI Builder** to design a separate screen by adding and arranging text,
   rectangles, circles, and lines on a 240x240 canvas.

## UI Builder

The builder opens from the simulator and starts with an editable example screen.
Manage screens with Add, Copy, Delete, and the screen selector. Select an element
from the Layers list or click it on the canvas, then drag it or edit its position,
size, text, and color in Properties. Use the layer controls to change draw order.
Projects containing multiple screens are saved as `.iintsui` JSON files and can
be reopened later. Screen PNG exports the active screen; Contact sheet exports
all screens together.

Export firmware creates a standalone MicroPython module with a `draw_<screen>(fb)`
function for each screen, plus `draw_custom_ui(fb)` as an alias for the first
screen. Each function draws onto an existing 240x240
`framebuf.FrameBuffer`; call it from the firmware and then call the firmware's
`flush()` to show it. The generated module does not initialize the display or
alter pump behavior. Firmware text uses the built-in 8x8 framebuffer font, so
it must contain ASCII characters. Always review exported UI code and test it on
the simulator before deploying it to pump hardware.

The screen list includes all 21 standard, Calm Mode, confirmation, maintenance,
sleep, and help views. Auto-reload watches the firmware source; restart the
simulator after changing `ui_simulator.py` itself.

The simulator uses fake GPIO, SPI, motor, and display modules. It cannot deliver
a dose or move the physical motor.

## Command-line contact sheet

```bash
python3 ui_simulator.py --contact-sheet previews/all_screens.png
```

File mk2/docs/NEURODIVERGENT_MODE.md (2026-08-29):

# IINTS-AF Calm Mode

Calm Mode is the neurodivergent-friendly interface for the Pico pump prototype.
It keeps the medical calculation unchanged while reducing visual and cognitive
load during normal monitoring and the guided bolus flow.

## Prototype Features

- One decision per screen with a fixed header, content area, and three button zones.
- Soft cool-white, grey, and muted-blue surfaces with dark readable text.
- Status is always written in words; colour is never the only signal.
- A small buddy image supports the reading without replacing the glucose value.
- Meal size uses four visible portions plus the exact carbohydrate amount.
- Delivery requires a separate adult review and a deliberate hold on `OK`.
- Calm Pause stops motor output and presents three short, predictable steps.
- Animations can be disabled in Settings without changing the calculations.

## Complete Pico Control Guide

- `GP16`: increase a value or move to the next choice.
- `GP17`: decrease a value, move to the previous choice, cancel, or stop delivery.
- `GP18`: select, confirm, or continue.
- Hold `GP16` on Home for 2.5 seconds: enter deep sleep.
- Hold `GP17` on Home for 0.9 seconds: open glucose history.
- Hold `GP18` on Adult Check: confirm delivery.
- Hold `GP18` in Rewind: run the motor backwards while held.
- Hold `GP16 + GP17` for 0.7 seconds: open or close Settings.
- Hold `GP16 + GP18` for 0.7 seconds in Calm Mode: open Calm Pause.
- Hold `GP17 + GP18` for 0.7 seconds: open or close the project demo image.
- Press any button while sleeping: wake the display.

The same guide is available on the pump under `Settings > Button guide`.

## Safety Note

This is a research prototype, not a certified medical device. UI and motor tests
should be performed with insulin disconnected and under qualified supervision.

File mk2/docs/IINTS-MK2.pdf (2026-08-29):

## An Educational Prototype of an Artificial Pancreas for Neurodivergent Learning

Bobbaers Rune

June 14, 2026

## Abstract

This project presents an educational prototype of an artificial pancreas, or insulin pump, developed within the IINTS vision of accessible science education. The device is not designed or certified for insulin administration in humans. Instead, it is a safe physical and digital model that demonstrates how complex diabetes-care technologies work. Internally, the prototype uses scientifically grounded computational models, including bi-exponential pharmacokinetic simulation, hydraulic volume calculations, PID closed-loop control, and state-feedback safety logic. Its educational purpose is twofold: to show that advanced medical algorithms can run on low-cost microcontrollers, and to provide a low-sensory interface that helps neurodivergent children understand Type 1 Diabetes in a safe simulation environment.

## 1 The History and Educational Vision of IINTS

Before discussing the technical design, it is important to define the context in which this prototype was created. The project was developed under the IINTS initiative. IINTS was not founded to compete with medical-device manufacturers, nor to produce illegal or unregulated medical devices. Its purpose is education, awareness, and scientific accessibility.

The pumps developed within IINTS are educational models. They are safe physical and digital prototypes designed to help patients, classmates, teachers, and medical students understand the technology behind diabetes care. By reconstructing a life-saving but often poorly understood device, the project demystifies the science of insulin pumps, artificial pancreas systems, and closed-loop control.

This particular prototype focuses on a group that is often overlooked in diabetes education: neurodivergent children. Instead of presenting diabetes technology only through abstract numbers and clinical terminology, the model uses visual, low-sensory interaction to make invisible biological processes more understandable.

## 2 Introduction

Type 1 Diabetes (T1D) is a chronic autoimmune condition in which the pancreas produces little or no insulin [1]. As a result, patients must learn how blood glucose, carbohydrates, insulin, physical activity, and timing interact. For children, this is already difficult; for neurodivergent children, the learning process can be made harder by cognitive overload, sensory stress, and interfaces that rely heavily on abstract numerical information.

Modern insulin pumps, continuous glucose monitors, and automated insulin-delivery systems are powerful technologies in diabetes care [2], but they are often experienced as closed, clinical, and difficult to understand. This can create distance between the user and the science that affects their daily life. The educational problem addressed by this project is therefore not only technical, but also pedagogical: how can complex diabetes technology be made visible, safe, and understandable?

This project proposes a low-sensory, open-source educational artificial pancreas prototype built around the Raspberry Pi Pico microcontroller. The prototype does not deliver insulin to humans. Instead, it simulates insulin delivery, glucose trends, and safety decisions in a controlled learning environment. Its purpose is to show that an affordable embedded system can combine realistic actuator mathematics, pharmacokinetic reasoning, and neurodivergent-friendly human–computer interaction.

## 3 Hardware Architecture

The educational prototype, named IINTS MK2, integrates a small set of low-cost embedded components selected for accessibility, reproducibility, and computational sufficiency. The central controller is a Raspberry Pi Pico based on the RP2040 microcontroller [18]. This platform is compact, inexpensive, widely documented, and powerful enough to run the required medical calculations in MicroPython while also controlling the display, buttons, and motor driver.

Motor actuation is handled through a DRV8833 motor driver [19], which provides bidirectional control of the pump actuator while isolating the microcontroller from the higher current requirements of the motor. Visual feedback is provided through an ST7789 TFT LCD screen [20]. This display allows the prototype to present both numerical information and simplified visual representations for the low-sensory interface mode. Together, these components create a physically realistic embedded platform for demonstrating artificial pancreas control logic without clinical use.

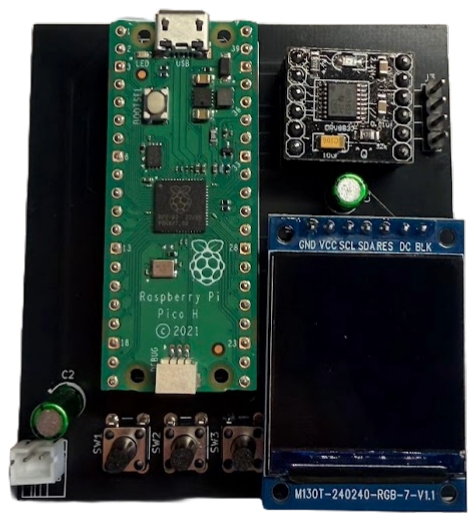
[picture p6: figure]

Figure 1. Physical IINTS MK2 educational artificial pancreas prototype. The photograph shows the compact IINTS MK2 pump model used to demonstrate actuator control, display feedback, and low-sensory interaction in a safe learning context.

## 4 Software Architecture

Medical software must remain responsive at all times. A pump interface should not freeze while the device waits for a sensor update, redraws a screen, or calculates a bolus. For this reason, the prototype software is structured as a non-blocking state machine in MicroPython. Instead of using long sleep() delays, the program compares timestamps using utime.ticks ms() and utime.ticks diff().

This architecture allows the pump to update the display, respond to buttons, process simulated CGM values, and evaluate safety formulas concurrently within the main loop. Listing 1 shows the timer-based structure used for real-time CGM simulation.

Listing 1: Non-blocking state machine for real-time CGM simulation

# Listing 1: Non-blocking state machine for real-time CGM simulation def update_cgm_sensor(force=False):

global huidige_bg, cgm_index, cgm_last_update_ms
now = utime.ticks_ms() # Get current time in milliseconds
elapsed_ms = utime.ticks_diff(now, cgm_last_update_ms)

# Update only if 60,000 ms (1 minute) have passed, without blocking the CPU if force or elapsed_ms >= CGM_UPDATE_MS:

steps = max(1, elapsed_ms // CGM_UPDATE_MS)
cgm_index = (cgm_index + steps) % len(CGM_PATTERN)
cgm_last_update_ms = now
huidige_bg = CGM_PATTERN[cgm_index]
return True

return False

As seen in Listing 1, the simulated sensor update is event-driven rather than delay-driven. This ensures that the processor remains available for interface updates and safety checks during every cycle of the program.

## 5 Biomechanics and Fluid Dynamics of the Actuator

Although the prototype is educational and not intended for human insulin delivery, realistic actuator mathematics are essential for demonstrating how real pumps calculate micro-doses. The stepper motor therefore imitates the fluid dynamics of a syringe-based pump using principles from hydraulics and cylindrical geometry.

### 5.1 Hydraulic Transmission: Pascal’s Principle

Insulin, as an aqueous solution, can be treated as practically incompressible in a first-order educational approximation. In the idealised model used here, the expelled volume is assumed to equal the mechanical reduction in reservoir volume. In real infusion systems, this relationship can be affected by compliance in the reservoir and tubing, backlash in the lead screw, trapped air, friction, pressure losses, and missed motor steps. The actuator in this project consists of a bipolar stepper motor connected to a lead screw that compresses a syringe-like reservoir.

### 5.2 Mathematical Volume and Dose Calculation

The conversion from GPIO signal to insulin-unit equivalent is modelled with the following assumptions. The dose values assume a 200-step motor; if an 18◦ per step micro linear stepper is used instead, the motor has only 20 steps per revolution and the per-step dose becomes ten times larger.

- Stepper motor assumption: Nsteps = 200 steps per revolution, corresponding to 1.8
- per
step.
- Lead screw pitch: p = 0.5 mm of linear displacement per revolution.
- Reservoir geometry: internal diameter 9.5 mm, giving r = 4.75 mm.

The volume conversion is:

Vrev = πr²

p = π · (4.75 mm)²

- 0.5 mm ≈ 35.44 mm³ = 35.44 µL,

Vstep =

Vrev

Nsteps

=

35.44 µL
200

≈ 0.177 µL/step.

For U-100 insulin, 1 unit = 10 µL. The insulin-unit conversion is therefore:

Drev =

35.44 µL
10 µL/unit

= 3.544 units,

Dstep =

0.177 µL/step
10 µL/unit

≈ 0.0177 units/step,

Steps per unit = | 1
| 0.0177

≈ 56.4 steps/unit.

Thus, the educational chain is GPIO signal → motor step → linear displacement → reservoir volume → insulin-unit equivalent. With a 20-step motor, the equivalent value would be approximately 0.177 units/step, ten times coarser than the 200-step assumption.

## 6 Pharmacokinetics: Bi-Exponential IOB Decay Model

A key learning objective of the model is the concept of active insulin, commonly referred to as Insulin On Board (IOB). In real diabetes care, tracking IOB is essential for preventing insulin stacking and the resulting risk of hypoglycaemia. Early insulin pumps often used simplified linear decay models, which assume that insulin activity disappears at a constant rate over time.

### 6.1 The Two-Compartment Bi-Exponential Model

In real pharmacokinetics, the absorption and clearance of subcutaneously administered insulin follow a complex two-compartment process: insulin first moves from subcutaneous tissue into the bloodstream and is then eliminated from circulation. To model this more realistically, the IINTS MK2 algorithm uses a bi-exponential approximation rather than a simplified quadratic curve. This approach is consistent with compartment-based modelling principles used in artificial pancreas research [5, 6].

The simulated active-insulin response is described as:

IOB(t) = Dose ·

ka
ka − ke
e

−ket − e

−kat

, | (1)

where ka is the absorption constant and ke is the elimination constant. The difference between these two exponential terms produces the characteristic rapid rise and long physiological tail of rapid-acting insulin.

In the MicroPython implementation, these exponential terms are calculated with the microcontroller’s mathematical library using math.exp. This allows the educational prototype to show that even a low-cost microcontroller can execute advanced pharmacokinetic calculations. For safety and clarity, the model is used for simulation and education only; it is not intended to determine real patient dosing.

Listing 2: Bi-exponential active-insulin calculation

def calculate_iob_biexponential(dose, elapsed_min, ka, ke): t = elapsed_min / 60.0 # minutes to hours
if t <= 0 or abs(ka - ke) < 0.0001:
return 0.0

activity = dose * (ka / (ka - ke)) * ( math.exp(-ke * t) - math.exp(-ka * t) )
return max(0.0, activity)

Listing 2 demonstrates how the mathematical model is translated into compact embedded code. By using exponentials directly, the IINTS MK2 can visualise the pharmacokinetic tail of insulin more faithfully than a straight-line decay model.

## 7 Control Theory: PID Controller for Closed-Loop Automation

A complete artificial pancreas does more than respond to manual bolus requests. It must continuously adjust basal insulin delivery based on the current glucose value and the simulated Continuous Glucose Monitor (CGM) trendline. In the IINTS MK2, this is demonstrated through a full PID controller, a classical feedback-control structure widely used in automation and closed-loop medical-device research [6, 8].

### 7.1 Proportional, Integral, Derivative Control

The controller calculates the error e(t) between the current blood glucose value and the target value once per simulated minute. This error is then weighted through three gains:

- Proportional (P): the current absolute deviation from the glucose target.
- Integral (I): the accumulated historical deviation, with windup restrictions to prevent excessive correction.
- Derivative (D): the rate of change of the glucose trendline, indicating whether glucose is rising or falling.

The resulting temporary basal adjustment is calculated as:

TempBasal(t) = Kp · e(t) + Ki

·

Z
e(t) dt + Kd ·

de(t)
dt . | (2)

This algorithm forms the educational core of closed-loop automation. It shows how a system can act before a glucose value becomes dangerously high or low, because the derivative term responds to the direction and speed of the trendline rather than only the current value. In the IINTS MK2, the PID output is limited by safety boundaries so that the demonstration remains bounded and interpretable.

## 8 Pharmacodynamics: Carbohydrate Absorption and Safety Algorithm

To calculate safe bolus behaviour in the simulation, the pump must also estimate how much glucose is still being absorbed from the digestive system. This quantity is referred to as Carbs On Board (COB). The algorithm integrates all meals recorded in the carb log over a medically standardised digestion time of 3 hours, or 180 minutes, for a mixed meal. A linear absorption model is applied:

COB(t) = Carbohydrates ·

1 −

telapsed

180 min
. | (3)

### 8.1 State Feedback and Conditional IOB Deduction

To demonstrate how artificial pancreas systems avoid overcompensation and integral windup, the software uses state feedback. The model shows how safety is built into meal-related dosing through a deductible-IOB limit:

Deductible IOB = max
0,IOB −

COB

ICR
, | (4)

where ICR is the insulin-to-carbohydrate ratio. This rule teaches users that active insulin is usually subtracted from a correction, except when that insulin is still needed to cover recently eaten carbohydrates. Only insulin that is effectively unassigned is deducted from the correction bolus. The final simulated dose is calculated as:

Total Dose = CarbBolus + CorrectionBolus − Deductible IOB. | (5)

Listing 3 shows how this safety concept is translated into MicroPython code.

Listing 3: The Deductible IOB safety algorithm

# Listing 3: The Deductible IOB Safety Algorithm

# We subtract active insulin (IOB) from the bolus, BUT we protect the insulin # that is reserved for digesting the stomach contents (COB).

# This prevents dangerous under-dosing (hyperglycemia) after a meal. cob_insulin_needed = cob / ICR

deductible_iob = max(0.0, iob - cob_insulin_needed)

# Calculate the final safe dose

berekende_dosis = carb_bolus + correction_bolus - deductible_iob # Ensure the pump never reverses or administers a negative dose totale_dosis = max(0.0, berekende_dosis)

As seen in Listing 3, the built-in max() function of MicroPython establishes a hard lower limit on deducted insulin and final dose output. As an educational demonstration, this formula links abstract control theory to an understandable safety concept: insulin can only be subtracted when it is not still needed for active carbohydrates.

## 9 Scientific Edge Cases and Advanced Logic

During development of the IINTS MK2 artificial pancreas simulation, several advanced clinical edge cases were identified and translated into mathematical logic. These cases are not included to enable real patient treatment, but to demonstrate that robust diabetes technology must respond to more than a single glucose value. Meals, sensor delay, circadian rhythm, and physical activity all change the meaning of the same numerical blood-glucose reading.

### 9.1 The “Pizza” Dual-Wave Bolus: Gastric Emptying

High-fat and high-protein meals can delay gastric emptying and extend postprandial glucose absorption, which is why real pump therapy often considers extended or dual-wave bolus strategies for meals such as pizza [9, 10]. In the Tamagotchi mode, selecting the “Pizza” portion automatically triggers a DUAL WAVE ACTIVE state. Mathematically, this changes the carbohydrate absorption window from the standard 3 hours to 6 hours:

Tabs =

(
180 min, standard meal,
360 min, dual-wave pizza mode.

(6)

This prevents the educational algorithm from modelling all carbohydrates as if they entered the bloodstream immediately. In practical terms, it teaches the user why a high-fat meal may cause a late hyperglycaemic rise even when the early glucose response appears safe.

### 9.2 Sensor Lag and Derivative Control

Continuous Glucose Monitors (CGMs) measure glucose in interstitial fluid rather than directly in capillary blood. This creates a physiological delay, often discussed in the range of several minutes, between the true blood-glucose trend and the sensor-reported value [11]. To demonstrate this limitation, the IINTS MK2 PID controller gives explicit educational importance to the derivative term, which estimates the direction and speed of glucose change.

The simplified prediction logic can be expressed as:

BGpredicted = BGCGM + τ ·

dBG
dt , | (7)

where τ represents an assumed sensor-lag horizon. This allows the simulation to show that the system should not only ask “What is the glucose now?”, but also “Where is the glucose going?”

### 9.3 Circadian Rhythm and the Dawn Phenomenon

Insulin sensitivity fluctuates over a 24-hour cycle because of hormonal rhythms, including early-morning counterregulatory hormones such as cortisol. The resulting dawn phenomenon can increase insulin needs in the early morning [12]. To demonstrate this, the code includes a get circadian isf() function that dynamically lowers the insulin sensitivity factor (ISF) between 04:00 and 08:00:

ISFeffective(t) = (
αdawn · ISFbase, 04:00 ≤ t < 08:00,
ISFbase, | otherwise,
0 < αdawn < 1. | (8)

Because correction insulin is inversely related to ISF, lowering the simulated ISF makes the model intervene more strongly against early-morning hyperglycaemia. This is presented as an educational demonstration of circadian physiology, not as a patient-specific dose rule.

### 9.4 Activity Mode and Physical Exercise

Physical activity can substantially increase insulin sensitivity and raise the risk of exercise-related hypoglycaemia in people with Type 1 Diabetes [13]. The IINTS MK2 therefore includes an ACTIVITY MODE. When enabled, the algorithm immediately raises the safe target glucose value and reduces PID aggressiveness:

T ARGETactivity = T ARGETbase + ∆activity, | Kactivity
p,i,d | = γ · Kbase
p,i,d , | 0 < γ < 1. | (9)

This teaches that safe closed-loop control is context-dependent: during exercise, a glucose value that would normally justify correction may instead require caution, basal reduction, or a higher temporary target.

## 10 Qualitative Validation & Expected Outcomes

Rather than conducting a quantitative clinical test, which falls outside the scope of an educational prototype, the UX design of the IINTS MK2 was qualitatively validated through empirical observations. These insights are directly informed by the author’s personal field experience as a youth camp counsellor (“moni”) at camps for neurodivergent children, including children with Autism Spectrum Disorder (ASD) and ADHD.

During these camps, medical actions—such as operating a complex insulin pump—were observed to cause acute overstimulation, frustration, and loss of autonomy in some children. Based on this practical field experience, the expected outcomes of the IINTS “Tamagotchi” interface are as follows:

- Reduction of cognitive overload: By replacing abstract numbers with a familiar Blueyinspired interface and photographs of meals, the task-initiation threshold for the child is expected to decrease substantially. A child may recognise “Pizza” faster than “60 g carbohydrates,” reducing uncertainty and performance anxiety.
- Increased medical sovereignty: In camp settings, children often hand over pump operation entirely to adults because they fear making mistakes with numerical inputs. The guided autonomous workflow allows the child to take the first step independently, strengthening ownership over their own body and care process.
- Prevention of alarm fatigue: Slow visual animations during simulated delivery replace shrill beeps, flashing warnings, and harsh alarm signals. This supports predictable and calm sensory processing, helping to prevent stress-related meltdowns at demanding moments such as mealtimes.

## 11 Cognitive Accessibility: Neurological and Visual Design

The most profound innovation of this educational prototype lies in the field of human–computer interaction (HCI) and psychology. Conventional medical devices are typically engineered by adults for clinical professionals, resulting in cold, number-heavy interfaces. For young children, and particularly neurodivergent users such as those with Autism Spectrum Disorder, ADHD, or dyslexia, this imposes an overwhelming cognitive load and sensory barrier [16, 17].

Medical Sovereignty (Autonomy). A critical flaw of standard insulin pumps is that their intimidating interfaces can render children entirely dependent on their parents to operate the machine. Abstract numerical data reduces the child to a passive “patient.” The primary goal of the IINTS interface is the restoration of medical sovereignty: by translating abstract medical data into the child’s own conceptual world, the child regains control and autonomy over their own body and disease management. They are no longer operating a “scary hospital machine,” but rather caring for a digital companion. This fosters independence, self-confidence, and disease acceptance at a significantly younger age.

Bridging the Experiential Gap (The MK2 Paradigm). Conventional insulin pumps are inherently foreign and intrusive to the experiential world of neurodivergent children and those with cognitive disabilities. To bridge this gap, the IINTS MK2 proposes integrating comforting, familiar cultural touchstones directly into the interface. For instance, the prototype explores the use of the widely recognised animated character “Bluey” as a digital companion. Because many children with varying degrees of cognitive disability find safety, regulation, and routine in familiar characters, adapting the medical device to their world—rather than forcing them to adapt to a clinical world—makes the pump significantly more manageable, approachable, and less alienating.

Happy
Glucose in range

Angry
High glucose

Sad
Low glucose

Figure 2. Example emotional glucose states used in the IINTS MK2 interface. The happy state represents a glucose value in range, the angry state represents hyperglycaemia, and the sad state represents hypoglycaemia.

Dual Coding Theory and Metaphorical Learning. The “Tamagotchi” mode actively reduces the dominance of intimidating clinical values, such as “120 mg/dL” or “30 g carbohydrates.” Instead, blood glucose levels are translated into facial expressions, such as happy, sleepy, or hyper, and carbohydrate inputs are represented by highly recognisable icons, such as an apple, a sandwich, or a pizza. Following Dual Coding Theory and Multimedia Learning principles [14, 15], coupling these visual metaphors with large, distinct text labels, such as “PIZZA,” reduces working-memory load. Even if the child is pre-literate or struggles with reading, the visual imagery supports word recognition and lowers the learning barrier.

Low-Sensory and Neuro-Inclusive Design. Neurodivergent children can be highly susceptible to visual and auditory sensory overload, which in a clinical context may contribute to alarm fatigue and severe stress responses. Reflecting universal-design principles [17], this interface deliberately avoids aggressive, overstimulating elements such as flashing progress bars, warning alarms, and harsh neon colours. Instead, it uses a calming palette of soft pastel colours. Furthermore, the typography uses high-contrast anthracite text instead of harsh pure black, softening the visual contrast and improving readability and comfort for dyslexic users.

## 12 Future Work

Because the IINTS pump is a purely educational model and not a certified medical device under medical-device regulation [21], future development focuses on educational and social impact rather than commercial clinical deployment.

The first priority is equal access to education. Patients, relatives, classmates, teachers, and healthcare students should be able to safely experiment with complex pump technology through a low-cost IINTS model. Many commercial diabetes technologies remain difficult to inspect, modify, or understand from an educational perspective. IINTS therefore explores how open educational models can make the underlying principles more accessible to students, patients, relatives, and healthcare learners.

The second priority is inclusion for neurodivergent users. This project acts as a call to action for the medical-technology industry: neurodivergent people must be considered from the beginning of medical interface design. Future work will therefore focus on broader design guidelines for low-sensory, cognitively accessible pump interfaces, so that accessibility becomes a default design requirement rather than an afterthought.

## 13 Conclusion

By combining actuator mechanics, simplified pharmacokinetic modelling, algorithmic reasoning, and low-sensory interface design, this project demonstrates how artificial pancreas technology can be transformed into an educational tool. The IINTS prototype does not claim to be a medical device; instead, it provides a safe way to learn, discuss, and visualise the scientific principles behind diabetes technology. In doing so, it argues that technical education, neurodivergent accessibility, and shared medical sovereignty should be central to the future of medical innovation.

## References

## References

[1] National Institute of Diabetes and Digestive and Kidney Diseases. “Type 1 Diabetes.” National Institutes of Health, 2024. Accessed 11 June 2026.
[2] American Diabetes Association Professional Practice Committee. “7. Diabetes Technology: Standards of Care in Diabetes—2026.” Diabetes Care, vol. 49, Supplement 1, 2026, pp. S150– S165. doi:10.2337/dc26-S007.
[3] Walsh, J., Roberts, R., and Heinemann, L. “Confusion Regarding Duration of Insulin Action: A Potential Source for Major Insulin Dose Errors by Bolus Calculators.” Journal of Diabetes Science and Technology, vol. 8, no. 1, 2014, pp. 170–178. doi:10.1177/1932296813514319.
[4] Walsh, J., Roberts, R., and Bailey, T. Pumping Insulin: Everything You Need for Success on a Smart Insulin Pump. 6th ed., Torrey Pines Press, 2017.
[5] Hovorka, R., Canonico, V., Chassin, L. J., Haueter, U., Massi-Benedetti, M., Federici, M. O., Pieber, T. R., Schaller, H. C., Schaupp, L., Vering, T., and Wilinska, M. E. “Nonlinear Model Predictive Control of Glucose Concentration in Subjects with Type 1 Diabetes.” Physiological Measurement, vol. 25, no. 4, 2004, pp. 905–920. doi:10.1088/0967-3334/25/4/010.
[6] Bequette, B. W. “A Critical Assessment of Algorithms and Challenges in the Development of a Closed-Loop Artificial Pancreas.” Diabetes Technology & Therapeutics, vol. 7, no. 1, 2005, pp. 28–47. doi:10.1089/dia.2005.7.28.
[7] Lewis, D. M., and Leibrand, S. “Real-World Use of Open Source Artificial Pancreas Systems.” Journal of Diabetes Science and Technology, vol. 10, no. 6, 2016, p. 1411. doi:10.1177/1932296816665635.
[8] OpenAPS Community. OpenAPS Reference Design: Principles of an Open Artificial Pancreas System. OpenAPS.org, accessed 11 June 2026.
[9] Wolpert, H. A., Atakov-Castillo, A., Smith, S. A., and Steil, G. M. “Dietary Fat Acutely Increases Glucose Concentrations and Insulin Requirements in Patients With Type 1 Diabetes.” Diabetes Care, vol. 36, no. 4, 2013, pp. 810–816. doi:10.2337/dc12-0092.
[10] Metwally, M., Cheung, T. O., Smith, R., and Bell, K. J. “Insulin Pump Dosing Strategies for Meals Varying in Fat, Protein or Glycaemic Index or Glycaemic Load: A Systematic Review.” Diabetes Research and Clinical Practice, vol. 172, 2021, 108516. doi:10.1016/j.diabres.2020.108516.
[11] Facchinetti, A. “Continuous Glucose Monitoring Sensors: Past, Present and Future Algorithmic Challenges.” Sensors, vol. 16, no. 12, 2016, 2093. doi:10.3390/s16122093.
[12] Monnier, L., Colette, C., and Owens, D. “The Dawn Phenomenon in Type 2 Diabetes: How to Assess It in Clinical Practice?” Diabetes & Metabolism, vol. 39, no. 1, 2013, pp. 3–9. doi:10.1016/j.diabet.2012.07.006.

[13] Riddell, M. C., Gallen, I. W., Smart, C. E., Taplin, C. E., Adolfsson, P., Lumb, A. N., Kowalski, A., Rabasa-Lhoret, R., McCrimmon, R. J., Hume, C., Annan, F., Fournier, P. A., Graham, C., Bode, B., Galassetti, P., Jones, T. W., Mill´an, I. S., Heise, T., Peters, A. L., Petz, A., and Laffel, L. M. “Exercise Management in Type 1 Diabetes: A Consensus Statement.” The Lancet Diabetes & Endocrinology, vol. 5, no. 5, 2017, pp. 377–390. doi:10.1016/S2213-8587(17)30014-1.
[14] Paivio, A. Mental Representations: A Dual Coding Approach. Oxford University Press, 1986.
[15] Mayer, R. E. Multimedia Learning. 2nd ed., Cambridge University Press, 2009.
[16] Sweller, J. “Cognitive Load During Problem Solving: Effects on Learning.” Cognitive Science, vol. 12, no. 2, 1988, pp. 257–285. doi:10.1207/s15516709cog1202 4.
[17] CAST. “Universal Design for Learning Guidelines, Version 3.0.” CAST, 2024. Accessed 11 June 2026.
[18] Raspberry Pi Ltd. RP2040 Datasheet: A Microcontroller by Raspberry Pi. Build version 3184e62, 2025.
[19] Texas Instruments. DRV8833 Dual H-Bridge Motor Driver Datasheet. Rev. E, July 2015.
[20] Sitronix Technology Corporation. ST7789V Single-Chip Controller/Driver for 262K-Color Graphic Type TFT-LCD Datasheet. Sitronix Technology Corporation.
[21] European Parliament and Council of the European Union. “Regulation (EU) 2017/745 of 5 April 2017 on Medical Devices.” Official Journal of the European Union, L 117, 5 May 2017.

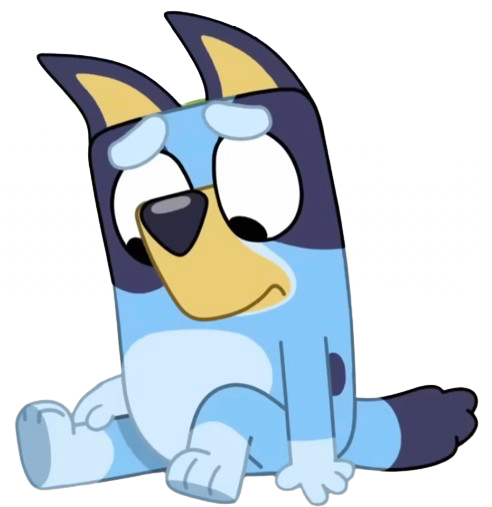
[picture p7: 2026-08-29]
mk2/assets/bluey/source/sad.png

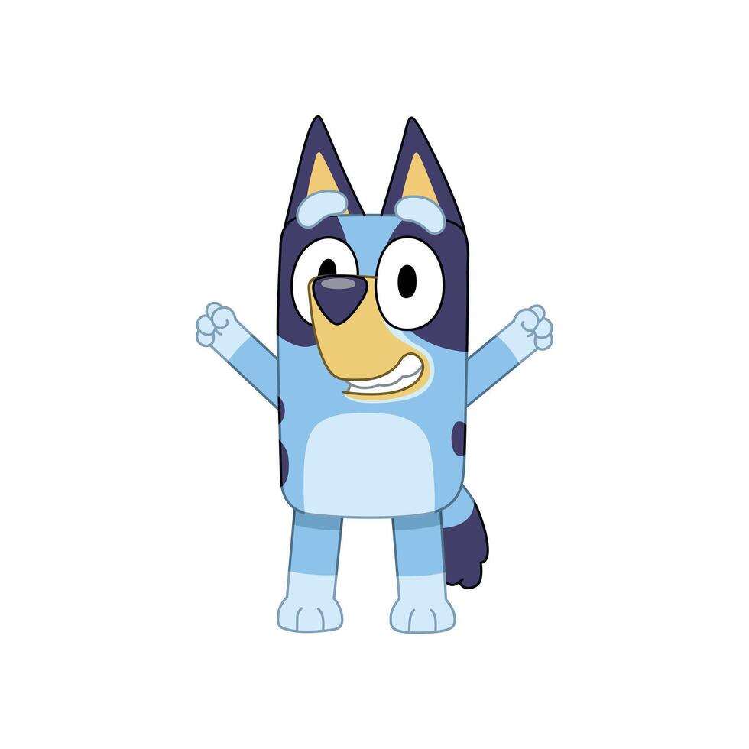
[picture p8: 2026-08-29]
mk2/assets/bluey/source/happy.jpg

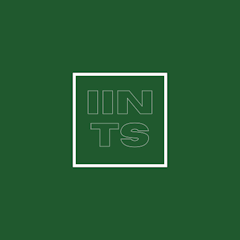
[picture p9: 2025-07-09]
start.bmp

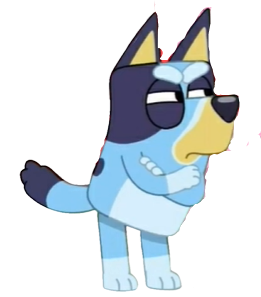
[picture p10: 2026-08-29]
mk2/assets/bluey/source/angry.png

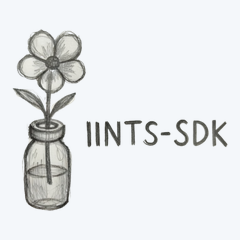
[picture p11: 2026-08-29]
mk2/assets/branding/start_preview.png

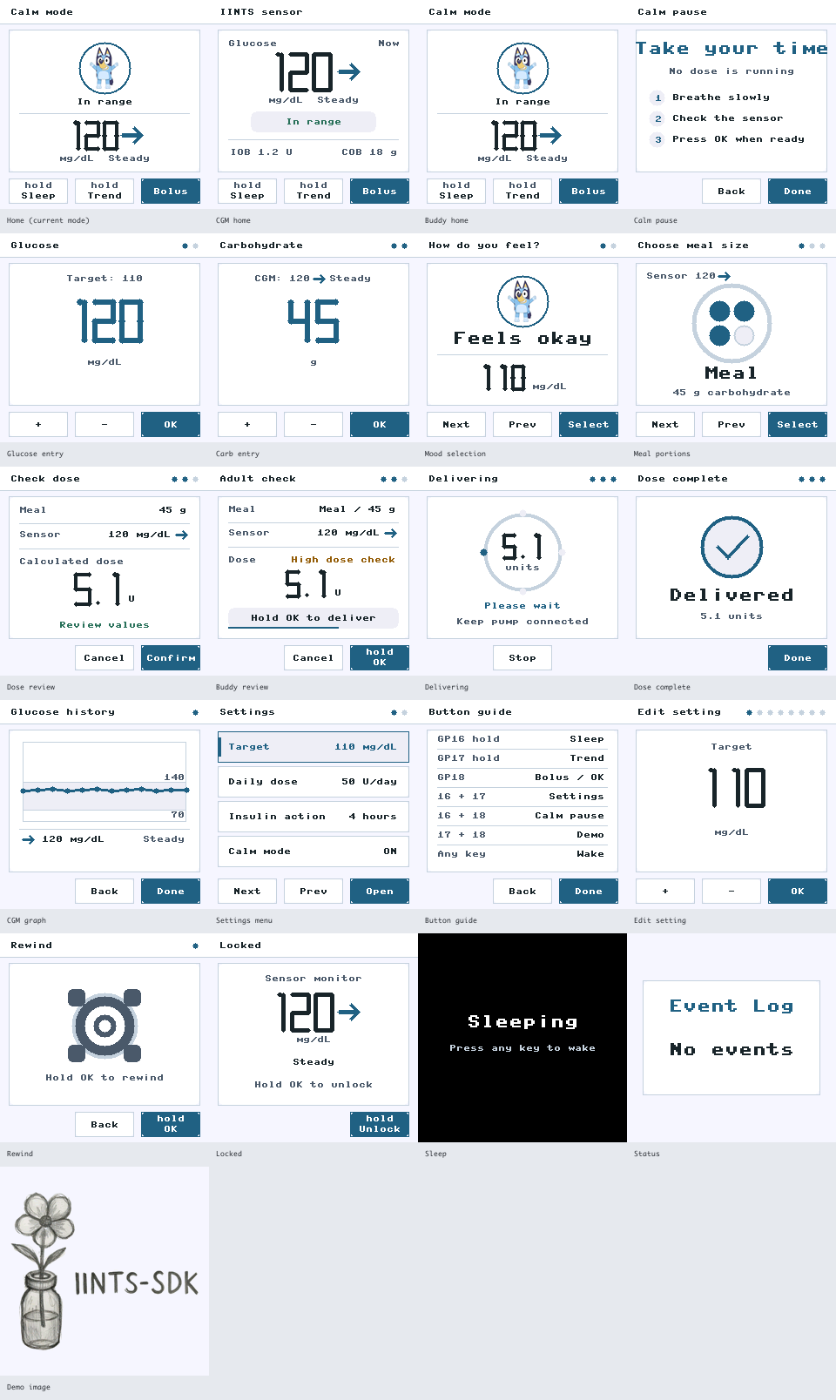
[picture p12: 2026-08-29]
mk2/simulator/previews/professional_ui_final.png

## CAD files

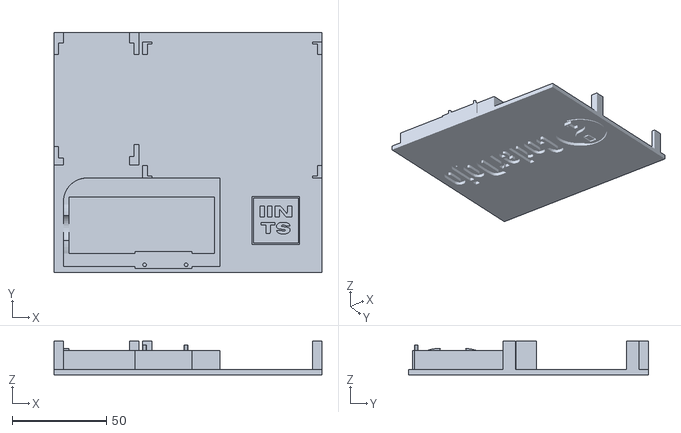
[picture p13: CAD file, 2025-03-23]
stl/v12.stl
142.0 x 127.0 x 18.0

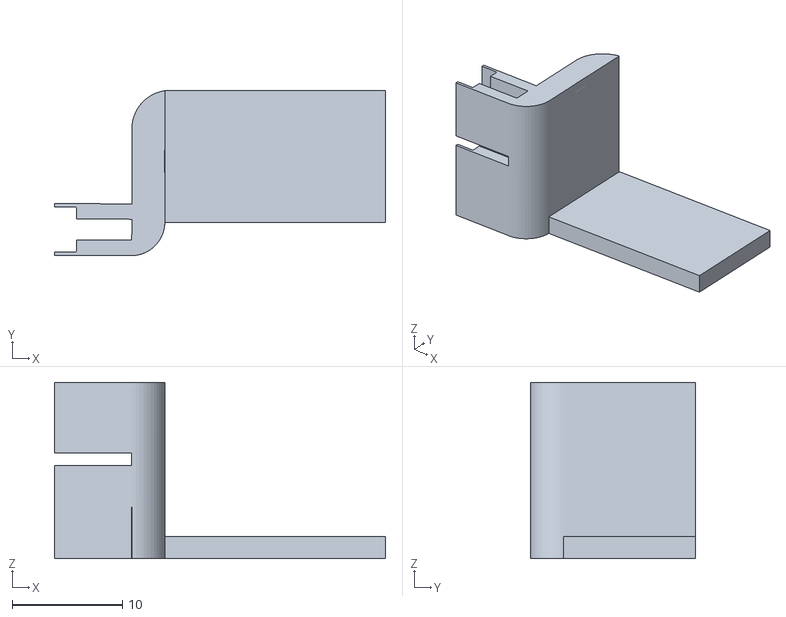
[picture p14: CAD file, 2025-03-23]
stl/v11opzet.stl
30.0 x 15.0 x 16.0

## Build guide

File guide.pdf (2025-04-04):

# DIY Insulin Pump Code Manual

This manual provides a detailed explanation of the code for a DIY insulin pump. It includes information on the functionality of each component and how the code works.

## IINTS Project Overview

IINTS (Insulin Is Not The Solution) is an open-source insulin pump project designed with affordability and accessibility in mind. It is built using MicroPython on a Raspberry Pi Pico and controls insulin delivery via stepper motors and a user-friendly interface.

Key Features:

## Project History

IINTS was founded in 2024 as a personal project to learn more about insulin pumps and their mechanics. As someone with 13 years of experience living with diabetes, I was curious about how these devices work and wanted to build one myself. While not intended as a commercial alternative, I share this project as an open-source learning experience for anyone interested in electronics, programming, and medical technology.

Major Milestones:

Special Thanks

A huge thank you to the coaches from CoderDojo Genk and Hasselt for their incredible guidance and support throughout this project. Their mentorship has been invaluable in bringing this idea to life!

## Project Features

Customizable
Affordable
Open-source
Made for everyone

May 2024: First working prototype with Raspberry Pi Pico
July 2024: OLED screen and user interface added
December 2024: Introduced microstepping for improved precision April 2025: Presentation at Coolest Projects Belgium

## Hardware Requirements

Core Hardware:

Insulin Pump Mechanism:

## 3D Print Files

All required 3D-printable parts can be found in the /stl folder.

## Recommended Print Settings

## 3D Print Timelapse

## Installation Guide

Stepper Motor Control: Precise insulin delivery using stepper motors User-Friendly Interface: Buttons and display for simple operation Safety Mechanisms: Basic fail-safes for reliable functioning Customizable: Adjust dosage and settings as needed
3D Printable: Open-source STL files for hardware
Open Source: Licensed under MIT, free for personal and medical research

Raspberry Pi Pico (RP2040)
OLED/TFT display (for UI)
Stepper motor + Driver (e.g., A4988, ULN2003) Push buttons (for input)
Battery / Power supply

Syringe pump setup (or peristaltic pump) 3D-printed mounts (STL files included!)

Download STL files: [STL Folder](link to STL folder)

Material: PLA or PETG
Layer height: 0.2mm
Infill: 20%
Supports: Not required
Bed adhesion: Brim or Skirt

Watch the 3D printing process in action! [Timelapse video](link to timelapse video)

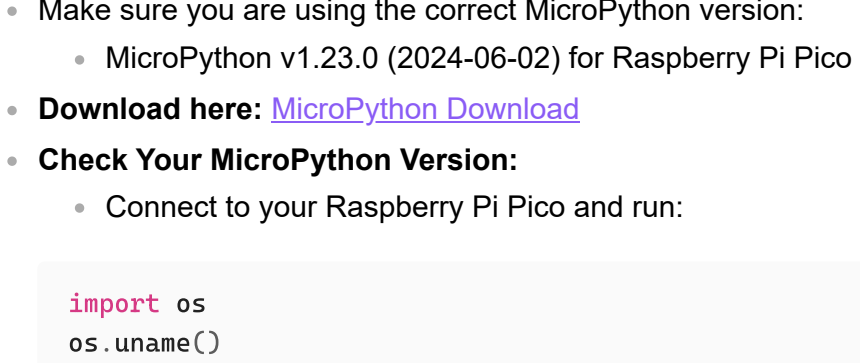
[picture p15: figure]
Download here: MicroPython Download; Check Your MicroPython Version:; import os; os.uname()
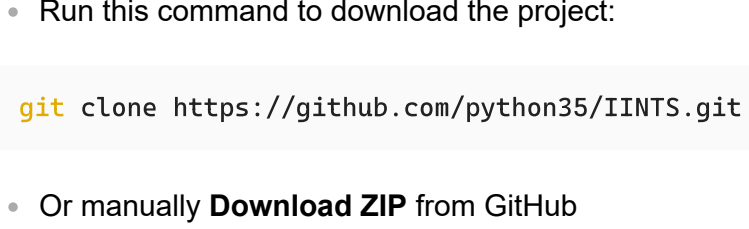
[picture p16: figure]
git clone https://github.com/python35/IINTS.git; Or manually Download ZIP from GitHub

## Configuration

1. Install MicroPython
Make sure you are using the correct MicroPython version: MicroPython v1.23.0 (2024-06-02) for Raspberry Pi Pico

Connect to your Raspberry Pi Pico and run:

2. Install Thonny IDE
Thonny is recommended for writing and uploading MicroPython scripts. Download: Thonny Download (https://thonny.org/)
Steps:
Open Thonny
Select Raspberry Pi Pico as the interpreter Install MicroPython firmware if not already installed
3. Clone This Repository
Run this command to download the project:
4. Upload to Raspberry Pi Pico
Connect the Raspberry Pi Pico via USB Open Thonny
Copy main.py and other files to the Pico Click Run

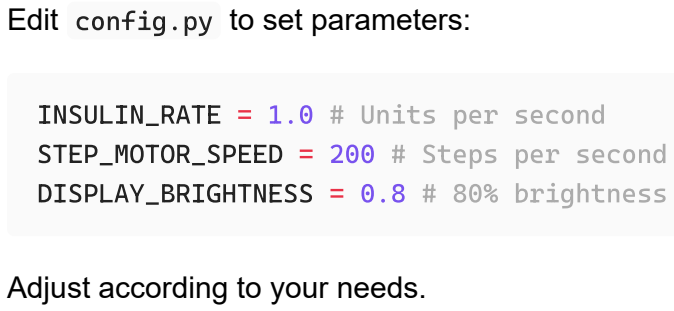
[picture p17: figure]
Edit config.py to set parameters:; Adjust according to your needs.; INSULIN_RATE = 1.0 # Units per second

STEP_MOTOR_SPEED = 200 # Steps per second

DISPLAY_BRIGHTNESS = 0.8 # 80% brightness

## License

This project is MIT Licensed, meaning you're free to use, modify, and distribute it. However, this is NOT a certified medical device — use responsibly.

## Contributions

Want to improve the project? Fork the repository and submit a Pull Request.

## Disclaimer

🚨 Warning: This project is for educational and research purposes only. It is not an FDA-approved medical device. Always consult a medical professional before using any insulin pump.

## Download & Start Building!

🔽 Clone the repository and start experimenting!

## 1. Libraries and Initialization

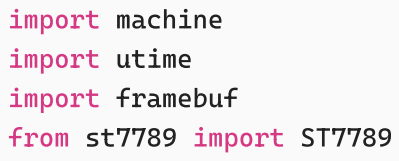
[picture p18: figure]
import machine; import utime; import framebuf; from st7789 import ST7789

## Libraries:

## Screen Initialization

machine : Provides access to the microcontroller’s hardware (in this case, a Pico), such as SPI, pins, etc.
utime : For time functions like sleep and sleep_ms .
framebuf : For creating a framebuffer, a memory area where you can draw pixels before sending them to the screen.
st7789 : A library for the ST7789 TFT LCD screen driver.

spi = machine.SPI(1, baudrate=40000000, polarity=1, phase=1,

sck=machine.Pin(10), mosi=machine.Pin(11))

dc = machine.Pin(13, machine.Pin.OUT)

reset = machine.Pin(12, machine.Pin.OUT)

bl = machine.Pin(17, machine.Pin.OUT)

display = ST7789(spi, 240, 240, reset=reset, dc=dc)

## 2. Text Function

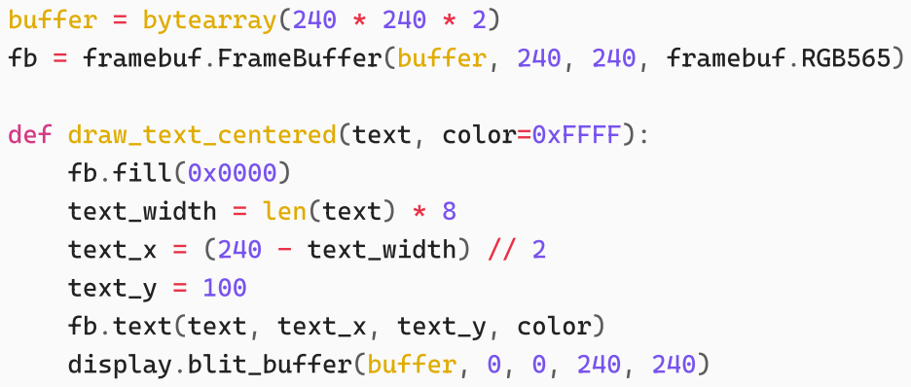
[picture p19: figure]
buffer = bytearray(240 * 240 * 2); def draw_text_centered(text, color=0xFFFF):; fb.fill(0x0000); text_width = len(text) * 8; text_x = (240 - text_width) // 2; text_y = 100; fb.text(text, text_x, text_y, color); display.blit_buffer(buffer, 0, 0, 240, 240)

## Framebuffer:

## Text function:

spi = machine.SPI(1, ...) : Initializes the SPI interface (Serial Peripheral Interface), used to communicate with the LCD screen. The parameters specify the SPI bus, speed, signal polarity and phase, and the pins used for SCK (Serial Clock) and MOSI (Master Output Slave Input).
dc = machine.Pin(13, machine.Pin.OUT) : Defines the Data/Command pin for the LCD. This pin is used to toggle between sending pixel data and commands.
reset = machine.Pin(12, machine.Pin.OUT) : Defines the reset pin for the LCD. A short signal to this pin resets the screen.
bl = machine.Pin(17, machine.Pin.OUT) : Defines the backlight pin for the LCD. Setting this pin high turns on the backlight.
display = ST7789(...) : Creates an ST7789 object representing the LCD screen. Parameters include the SPI interface, screen width and height, and the data/command and reset pins.
display.init() : Initializes the LCD screen by sending a sequence of commands to set it up.
bl.value(1) : Turns on the screen backlight.

fb = framebuf.FrameBuffer(buffer, 240, 240, framebuf.RGB565)

buffer = bytearray(240 * 240 * 2) : Creates a bytearray large enough to hold pixel data for the entire screen (240x240 pixels, 2 bytes per pixel for RGB565 color).
fb = framebuf.FrameBuffer(...) : Creates a FrameBuffer object which allows you to draw on the buffer using pixel and shape functions. RGB565 is a 16-bit color format.

## 3. Startup Screen Function

show_startup_screen() : Displays a BMP image on startup.

draw_text_centered(text, color=0xFFFF) : Draws centered text on the screen. fb.fill(0x0000) : Clears the framebuffer (fills it with black).
text_width = len(text) * 8 : Calculates the text width (each character is 8 pixels wide).
text_x = (240 - text_width) // 2 : Calculates the X position to center the text horizontally.
text_y = 100 : Sets the vertical position of the text.
fb.text(...) : Draws the text to the framebuffer with the specified color. display.blit_buffer(...) : Sends the framebuffer content to the display.

def show_startup_screen():

try:

with open("start.bmp", "rb") as f:

f.seek(18)

bmp_width = int.from_bytes(f.read(4), 'little')

bmp_height = int.from_bytes(f.read(4), 'little')

f.seek(54) # Start of pixel data

x_offset = ((240 - bmp_width) // 2) - 40

y_offset = (240 - bmp_height) // 2

row_buffer = bytearray(bmp_width * 2)

display.fill(0x22C5)

for y in range(bmp_height):

f.readinto(row_buffer)

f.seek(54 + (bmp_height - 1 - y) * bmp_width * 2)

for i in range(0, len(row_buffer), 2):

row_buffer[i], row_buffer[i + 1] = row_buffer[i + 1],

row_buffer[i]

display.blit_buffer(row_buffer, x_offset, y + y_offset,

bmp_width, 1)

utime.sleep(5)

except OSError:

draw_text_centered("BMP not found", color=0xFFFF)

utime.sleep(3)

display.fill(0x000000)

try...except OSError : Attempts to load the BMP image; if not found, displays an error message.

## 4. Button Configuration

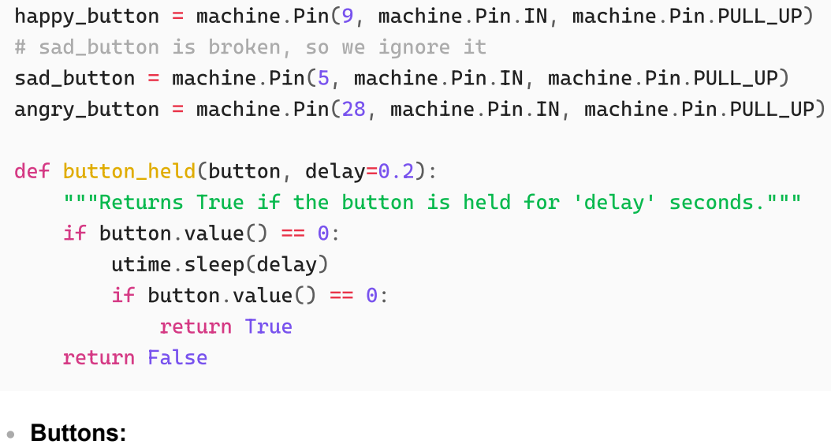
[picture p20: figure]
happy_button = machine.Pin(9, machine.Pin.IN, machine.Pin.PULL_UP); # sad_button is broken, so we ignore it; sad_button = machine.Pin(5, machine.Pin.IN, machine.Pin.PULL_UP); angry_button = machine.Pin(28, machine.Pin.IN, machine.Pin.PULL_UP); def button_held(button, delay=0.2):; if button.value() == 0:; utime.sleep(delay); return True; return False; Buttons:

## 5. Motor Configuration

Reads BMP metadata (width and height), and pixel data from offset 54.
Calculates x_offset and y_offset to center the image, shifted 40 pixels to the left. Reads each row of the image bottom-to-top (BMP stores pixels upside-down).
Swaps byte order from BGR to RGB.
display.fill(...) : Fills background with a color before showing the image.
If the image is not found, shows a centered "BMP not found" message.

"""Returns True if the button is held for 'delay' seconds."""

Buttons use PULL_UP , meaning they read 1 by default, and 0 when pressed.
Only the happy and angry buttons are functional.
button_held(...) checks if a button remains pressed for a short time to avoid accidental presses.

in1 = machine.Pin(2, machine.Pin.OUT)

in2 = machine.Pin(3, machine.Pin.OUT)

in3 = machine.Pin(4, machine.Pin.OUT)

in4 = machine.Pin(6, machine.Pin.OUT)

def disable_motor():

in1.value(0)

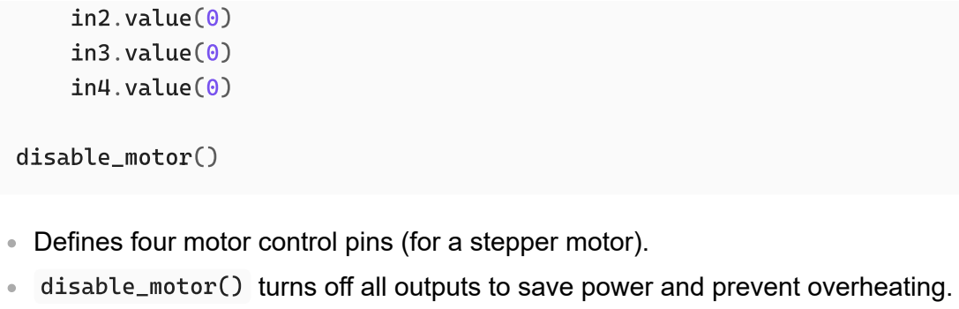
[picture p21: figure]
in2.value(0); in3.value(0); in4.value(0); disable_motor()

## 6. Stepper Motor Functions

Defines four motor control pins (for a stepper motor).
disable_motor() turns off all outputs to save power and prevent overheating.

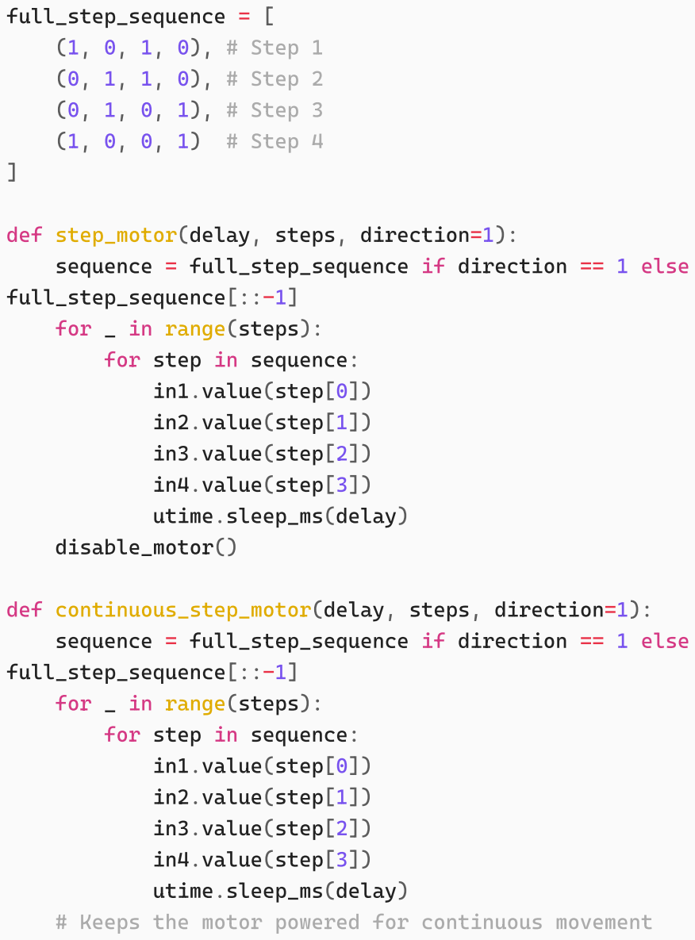
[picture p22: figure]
full_step_sequence = [; (1, 0, 1, 0), # Step 1; (0, 1, 1, 0), # Step 2; (0, 1, 0, 1), # Step 3; # Step 4; def step_motor(delay, steps, direction=1):; full_step_sequence[::-1]; for _ in range(steps):; for step in sequence:; in1.value(step[0]); in2.value(step[1]); in3.value(step[2]); in4.value(step[3]); utime.sleep_ms(delay); disable_motor(); def continuous_step_motor(delay, steps, direction=1):

sequence = full_step_sequence if direction == 1 else

sequence = full_step_sequence if direction == 1 else

# Keeps the motor powered for continuous movement

## 7. Variables and Value Change

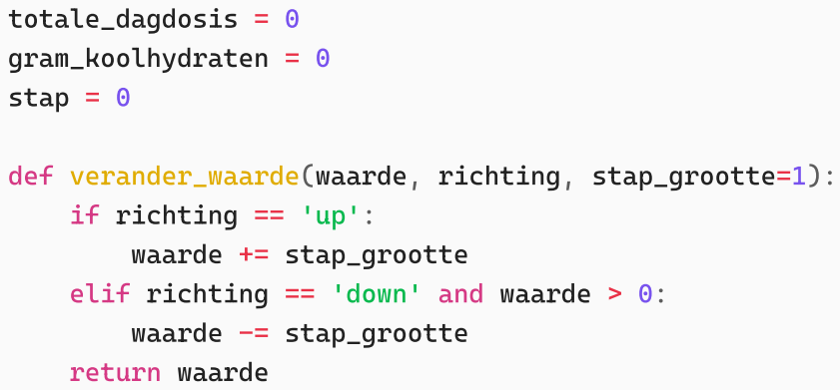
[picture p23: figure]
totale_dagdosis = 0; gram_koolhydraten = 0; stap = 0; def verander_waarde(waarde, richting, stap_grootte=1):; if richting == 'up':; waarde += stap_grootte; elif richting == 'down' and waarde > 0:; waarde -= stap_grootte; return waarde

## 8. Main Program

full_step_sequence : Sequence of signals to drive the stepper motor. step_motor(...) : Moves a set number of steps, then turns off the motor. continuous_step_motor(...) : Used to keep the motor running (e.g., during manual retraction).

totale_dagdosis : Total daily insulin dose.
gram_koolhydraten : Amount of carbs to be injected for.
stap : Tracks the current phase (0 = daily dose, 1 = carbs, 2 = inject). verander_waarde(...) : Helper to increase/decrease a value with optional step size.

show_startup_screen()

while True:

# Step 0: Set total daily dose

if stap == 0:

draw_text_centered(f"Day dose: {totale_dagdosis}U")

if button_held(happy_button, delay=0.3):

totale_dagdosis = verander_waarde(totale_dagdosis, 'up')

draw_text_centered(f"Day dose: {totale_dagdosis}U")

if button_held(angry_button, delay=0.3) and totale_dagdosis > 0:

stap = 1

utime.sleep(0.3)

# Step 1: Set carbs in grams

elif stap == 1:

draw_text_centered(f"Carbs: {gram_koolhydraten}g")

if button_held(happy_button, delay=0.3):

gram_koolhydraten = verander_waarde(gram_koolhydraten, 'up')

draw_text_centered(f"Carbs: {gram_koolhydraten}g")

if button_held(angry_button, delay=0.3) and gram_koolhydraten > 0:

stap = 2

utime.sleep(0.3)

# Step 2: Calculate insulin and inject

elif stap == 2:

kh_ratio = 500 / totale_dagdosis

eenheden_insuline = gram_koolhydraten / kh_ratio

steps_per_revolution = 200

insuline_per_revolution = 1.0

steps_per_unit_insuline = steps_per_revolution /

insuline_per_revolution

total_steps = int(eenheden_insuline * steps_per_unit_insuline)

step_motor(5, total_steps, direction=-1)

draw_text_centered(f"Insulin: {eenheden_insuline:.2f}U")

utime.sleep(2)

draw_text_centered("Retract?")

utime.sleep(1)

while angry_button.value() == 0:

continuous_step_motor(5, 10, direction=1)

utime.sleep(0.1)

disable_motor()

draw_text_centered("Motor retracted")

utime.sleep(2)

totale_dagdosis = 0

gram_koolhydraten = 0

stap = 0

Step 0: User sets total daily insulin dose.
Step 1: User sets carbs in grams.
Step 2:
Calculates required insulin using the 500 rule. Converts insulin units into motor steps.

## Scientific Explanation of Insulin Calculation

The calculation of insulin units in this DIY insulin pump is based on a fundamental concept in diabetes management: the carbohydrate ratio (CR). Here is a detailed explanation:

## 1. Carbohydrate Ratio (CR)

The CR is a measure of how many grams of carbohydrates are compensated by one unit of insulin. This ratio is individually determined and can vary depending on factors such as:

In the code, the CR is calculated using the following formula:

This formula is a simplification. The value '500' is a general guideline, but in clinical practice, the rule of 450 or 500 is often used to divide the total daily dose of insulin to obtain an estimate of the carbohydrate ratio. This number (450 or 500) represents an estimate of the total amount of carbohydrates (in grams) that can be metabolized by one unit of insulin over a certain period.

Example: If someone uses a total daily dose of 25 units of insulin, the CR is:

This means that 1 unit of insulin can process 20 grams of carbohydrates.

## 2. Calculating Insulin Needs

Once the CR is known, the required amount of insulin for a specific meal can be calculated using the following formula:

Injects insulin ( direction=-1 ).
Asks if retraction is needed.
While "angry" button is pressed, the motor retracts ( direction=1 ). Resets variables and returns to step 0.

Insulin sensitivity: Some people are more sensitive to insulin than others. Time of day: Insulin sensitivity can vary throughout the day.
Activity level: Physical activity increases insulin sensitivity.

cr = 500 / total_daily_dose

cr = 500 / 25 = 20

units_of_insulin = grams_of_carbohydrates / cr

Example: If the person wants to consume 60 grams of carbohydrates and the CR is 20, then the required amount of insulin is:

## 3. Calculating Motor Steps

The code converts the calculated insulin units into the number of steps the stepper motor needs to rotate to deliver the correct dose.

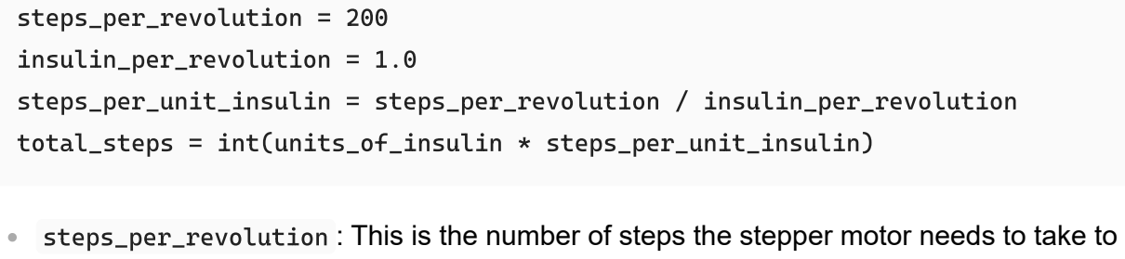
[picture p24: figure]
steps_per_revolution = 200; insulin_per_revolution = 1.0; total_steps = int(units_of_insulin * steps_per_unit_insulin)

Example: If the stepper motor takes 200 steps per revolution and 1 revolution delivers 1 unit of insulin, and the calculated dose is 3 units, then the total number of steps is:

Total daily dose: This is the total amount of insulin (in units) that a person needs per day. This value is usually determined by a doctor.
Grams of carbohydrates: This is the amount of carbohydrates (in grams) that the person plans to consume.
Units of insulin: The calculated amount of insulin needed to process the consumed carbohydrates.

units_of_insulin = 60 / 20 = 3 units

steps_per_unit_insulin = steps_per_revolution / insulin_per_revolution

steps_per_revolution : This is the number of steps the stepper motor needs to take to complete one full revolution. This value depends on the motor used. insulin_per_revolution : This is the amount of insulin (in units) delivered for one full revolution of the motor. This value depends on the mechanical setup of the pump (e.g., the lead of the syringe screw). This is the calibration constant and is crucial for the accuracy of the pump.
steps_per_unit_insulin : The number of steps the motor needs to take to deliver one unit of insulin.
total_steps : The total number of steps the motor needs to take to deliver the calculated amount of insulin. The result is rounded down to a whole number using int() .

steps_per_unit_insulin = 200 / 1 = 200 steps/unit

Important Considerations

Calibration: The value of insulin_per_revolution is crucial and must be accurately calibrated. Any deviation in this value will lead to incorrect insulin dosing.
Accuracy: The accuracy of insulin delivery depends on the accuracy of the stepper motor, the mechanical construction of the pump, and correct calibration.
Safety: Incorrect calculations or inaccurate insulin delivery can have serious health consequences. It is of the utmost importance that the code and hardware are thoroughly tested and validated in a safe environment. Always consult a qualified healthcare professional for advice on diabetes management.

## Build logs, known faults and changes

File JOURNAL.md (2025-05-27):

---
title: "IINTS - DIY Insulin Pump"
author: "Rune Bobbaers"
description: "A DIY open-source insulin pump project to explore how medical devices work."
created_at: "2025-05-26"
---

# May 26: Setup & Documentation

Started prepping this project for Hack Club Highway!  
The repo was already live but I’m organizing everything better and writing this journal to log my progress.

**Total time spent: 1h**

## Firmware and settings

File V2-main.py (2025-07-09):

import machine
import utime
import framebuf
from st7789 import ST7789

# --- Scherminitialisatie ---
spi = machine.SPI(1, baudrate=40000000, polarity=1, phase=1,
                   sck=machine.Pin(10), mosi=machine.Pin(11))
dc = machine.Pin(13, machine.Pin.OUT)
reset = machine.Pin(12, machine.Pin.OUT)
bl = machine.Pin(17, machine.Pin.OUT)

display = ST7789(spi, 240, 240, reset=reset, dc=dc)
display.init()
bl.value(1)

# --- Tekstfunctie ---
buffer = bytearray(240 * 240 * 2)
fb = framebuf.FrameBuffer(buffer, 240, 240, framebuf.RGB565)


def draw_text_centered(text, color=0xFFFF):
    fb.fill(0x0000)
    text_width = len(text) * 8
    text_x = (240 - text_width) // 2
    text_y = 100
    fb.text(text, text_x, text_y, color)
    display.blit_buffer(buffer, 0, 0, 240, 240)

# --- Startup-scherm functie ---
def show_startup_screen():
    try:
        with open("start.bmp", "rb") as f:
            f.seek(18)
            bmp_width = int.from_bytes(f.read(4), 'little')
            bmp_height = int.from_bytes(f.read(4), 'little')
            f.seek(54)  # Begin van de pixeldata

            # Bereken positie: gecentreerd en iets naar links verschoven
            x_offset = ((240 - bmp_width) // 2) - 40
            y_offset = (240 - bmp_height) // 2

            row_buffer = bytearray(bmp_width * 2)

            display.fill(0x22C5)
            for y in range(bmp_height):
                f.seek(54 + (bmp_height - 1 - y) * bmp_width * 2)
                f.readinto(row_buffer)
                for i in range(0, len(row_buffer), 2):
                    row_buffer[i], row_buffer[i + 1] = row_buffer[i + 1], row_buffer[i]
                display.blit_buffer(row_buffer, x_offset, y + y_offset, bmp_width, 1)
            utime.sleep(5)  # Afbeelding 5 seconden zichtbaar
    except OSError:
        draw_text_centered("BMP niet gevonden", color=0xFFFF)
        utime.sleep(3)
    display.fill(0x000000)

# --- Knopconfiguratie ---
happy_button = machine.Pin(9, machine.Pin.IN, machine.Pin.PULL_UP)
# De sad-button is defect, dus we negeren deze
sad_button = machine.Pin(5, machine.Pin.IN, machine.Pin.PULL_UP)
angry_button = machine.Pin(28, machine.Pin.IN, machine.Pin.PULL_UP)

# We gaan geen wacht-for-release gebruiken, maar continu de knopstatus checken.
def button_held(button, delay=0.2):
    """Return True als de knop ingedrukt blijft gedurende 'delay' seconden."""
    if button.value() == 0:
        utime.sleep(delay)
        if button.value() == 0:
            return True
    return False

# --- Motorconfiguratie ---
in1 = machine.Pin(2, machine.Pin.OUT)
in2 = machine.Pin(3, machine.Pin.OUT)
in3 = machine.Pin(4, machine.Pin.OUT)
in4 = machine.Pin(6, machine.Pin.OUT)

def disable_motor():
    in1.value(0)
    in2.value(0)
    in3.value(0)
    in4.value(0)

disable_motor()

# --- Full-step sequentie (volgens testcode) ---
full_step_sequence = [
    (1, 0, 1, 0),  # Stap 1
    (0, 1, 1, 0),  # Stap 2
    (0, 1, 0, 1),  # Stap 3
    (1, 0, 0, 1)   # Stap 4
]

def step_motor(delay, steps, direction=1):
    """
    Draait de motor met de full-step sequentie.
      - Voor injectie: we gebruiken nu direction=-1 (omgekeerd ten opzichte van testcode)
      - Voor terugdraaien: direction=1
    """
    sequence = full_step_sequence if direction == 1 else full_step_sequence[::-1]
    for _ in range(steps):
        for step in sequence:
            in1.value(step[0])
            in2.value(step[1])
            in3.value(step[2])
            in4.value(step[3])
            utime.sleep_ms(delay)
    disable_motor()

def continuous_step_motor(delay, steps, direction=1):
    """
    Draait de motor continu (zonder uit te schakelen) in kleine stapjes,
    zodat deze blijft draaien zolang de knop ingedrukt is.
    """
    sequence = full_step_sequence if direction == 1 else full_step_sequence[::-1]
    for _ in range(steps):
        for step in sequence:
            in1.value(step[0])
            in2.value(step[1])
            in3.value(step[2])
            in4.value(step[3])
            utime.sleep_ms(delay)
    # Geen disable_motor() hier zodat de motor blijft draaien

# --- Variabelen ---
totale_dagdosis = 0
gram_koolhydraten = 0
stap = 0

def verander_waarde(waarde, richting, stap_grootte=1):
    if richting == 'omhoog':
        waarde += stap_grootte
    elif richting == 'omlaag' and waarde > 0:
        waarde -= stap_grootte
    return waarde

# --- Hoofdprogramma ---
show_startup_screen()

while True:
    # Stap 0: Stel totale dagdosis in
    if stap == 0:
        draw_text_centered(f"Dagdos: {totale_dagdosis}U")
        utime.sleep(1)
        if button_held(happy_button, delay=0.3):
            totale_dagdosis = verander_waarde(totale_dagdosis, 'omhoog')
            draw_text_centered(f"Dagdos: {totale_dagdosis}U")
        # sad_button is defect, dus geen verlagen
        if button_held(angry_button, delay=0.3) and totale_dagdosis > 0:
            stap = 1
            utime.sleep(0.3)
    
    # Stap 1: Stel gram koolhydraten in
    elif stap == 1:
        draw_text_centered(f"Koolhydr: {gram_koolhydraten}g")
        if button_held(happy_button, delay=0.3):
            gram_koolhydraten = verander_waarde(gram_koolhydraten, 'omhoog')
            draw_text_centered(f"Koolhydr: {gram_koolhydraten}g")
        # sad_button is defect, dus geen verlagen
        if button_held(angry_button, delay=0.3) and gram_koolhydraten > 0:
            stap = 2
            utime.sleep(0.3)
    
    # Stap 2: Bereken insuline, injecteer, en laat motor terugdraaien
    elif stap == 2:
        kh_ratio = 500 / totale_dagdosis
        eenheden_insuline = gram_koolhydraten / kh_ratio
        steps_per_revolution = 200
        insuline_per_revolution = 1.0
        steps_per_unit_insuline = steps_per_revolution / insuline_per_revolution
        total_steps = int(eenheden_insuline * steps_per_unit_insuline)
        
        # Injectie: Gebruik direction=-1 zodat de motor draait in jouw gewenste "vooruit" richting.
        step_motor(5, total_steps, direction=-1)
        draw_text_centered(f"Insuline: {eenheden_insuline:.2f}U")
        utime.sleep(2)
        
        draw_text_centered("terugdraaien?")
        utime.sleep(1)
        # Terugdraaien: Gebruik direction=1 en blijf draaien zolang de knop ingedrukt is.
        while angry_button.value() == 0:
            continuous_step_motor(5, 10, direction=1)
            utime.sleep(0.1)
        disable_motor()
        draw_text_centered("Motor teruggedraaid")
        utime.sleep(2)
        
        # Reset de waarden en ga terug naar stap 0
        totale_dagdosis = 0
        gram_koolhydraten = 0
        stap = 0

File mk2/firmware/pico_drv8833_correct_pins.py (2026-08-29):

import machine
import utime
import framebuf
import gc
from st7789 import ST7789

# --- Pin mapping ---
PIN_DRV_EEP = 28

PIN_MOTOR_IN1 = 4
PIN_MOTOR_IN2 = 5
PIN_MOTOR_IN3 = 6
PIN_MOTOR_IN4 = 9

PIN_DISPLAY_SCK = 10
PIN_DISPLAY_SDA = 11
PIN_DISPLAY_RES = 12
PIN_DISPLAY_DC = 13

PIN_BUTTON_1 = 16
PIN_BUTTON_2 = 17
PIN_BUTTON_3 = 18

# --- DRV8833 enable ---
drv_eep = machine.Pin(PIN_DRV_EEP, machine.Pin.OUT)
drv_eep.value(1)

# --- Onboard status LED ---
try:
    onboard_led = machine.Pin("LED", machine.Pin.OUT)
except Exception:
    try:
        onboard_led = machine.Pin(25, machine.Pin.OUT)
    except Exception:
        onboard_led = None


def set_delivery_led(is_on):
    if onboard_led is not None:
        onboard_led.value(1 if is_on else 0)


set_delivery_led(False)

# --- Scherminitialisatie ---
spi = machine.SPI(
    1,
    baudrate=40000000,
    polarity=1,
    phase=1,
    sck=machine.Pin(PIN_DISPLAY_SCK),
    mosi=machine.Pin(PIN_DISPLAY_SDA),
)
dc = machine.Pin(PIN_DISPLAY_DC, machine.Pin.OUT)
reset = machine.Pin(PIN_DISPLAY_RES, machine.Pin.OUT)

display = ST7789(spi, 240, 240, reset=reset, dc=dc)
display.init()

# BLK zit volgens de mapping direct op Pico 3V3, dus geen GPIO nodig.
ST7789_DISPOFF = 0x28
ST7789_SLPIN = 0x10
ST7789_SLPOUT = 0x11
ST7789_DISPON = 0x29

# --- Grafische UI ---
WIDTH = 240
HEIGHT = 240


def rgb565(r, g, b):
    # Convert to 16-bit RGB565 and swap bytes for MicroPython's little-endian FrameBuffer
    c = ((r & 0xF8) << 8) | ((g & 0xFC) << 3) | (b >> 3)
    return ((c & 0xFF) << 8) | ((c >> 8) & 0xFF)


# --- Rustig IPS-palet: neutraal, hoog contrast en niet afhankelijk van kleur ---
COLOR_BG = rgb565(244, 247, 249)        # Zacht koelwit
COLOR_PANEL = rgb565(255, 255, 255)     # Primaire oppervlakken
COLOR_PANEL_2 = rgb565(232, 238, 243)   # Rustige selectie/status
COLOR_EDGE = rgb565(198, 208, 216)      # Scheiding zonder hard contrast
COLOR_SHADOW = rgb565(224, 230, 234)
COLOR_TEXT = rgb565(28, 38, 46)         # Donker antraciet
COLOR_MUTED = rgb565(75, 91, 104)       # Leesbare secundaire tekst
COLOR_FOCUS = rgb565(38, 96, 134)       # Gedempt klinisch blauw
COLOR_MINT = rgb565(38, 96, 134)
COLOR_SUCCESS = rgb565(43, 112, 92)     # Alleen aanvullend op een tekstlabel
COLOR_CORAL = rgb565(174, 61, 64)
COLOR_AMBER = rgb565(145, 94, 8)
COLOR_BLUE = rgb565(38, 96, 134)
COLOR_BLACK = 0x0000
COLOR_WHITE = 0xFFFF

gc.collect()
buffer = bytearray(WIDTH * HEIGHT * 2)
fb = framebuf.FrameBuffer(buffer, WIDTH, HEIGHT, framebuf.RGB565)
char_buffer = bytearray(8 * 8 * 2)
char_fb = framebuf.FrameBuffer(char_buffer, 8, 8, framebuf.RGB565)
raw_image_row_buffer = bytearray(64 * 2)
raw_image_row_view = memoryview(raw_image_row_buffer)
raw_bg_pixel = bytearray(2)
raw_bg_fb = framebuf.FrameBuffer(raw_bg_pixel, 1, 1, framebuf.RGB565)


def flush():
    display.blit_buffer(buffer, 0, 0, WIDTH, HEIGHT)


def clear(color=COLOR_BG):
    fb.fill(color)


def fill_circle(cx, cy, radius, color):
    r2 = radius * radius
    for yy in range(-radius, radius + 1):
        span = int((r2 - yy * yy) ** 0.5)
        fb.hline(cx - span, cy + yy, span * 2 + 1, color)


def fill_round_rect(x, y, w, h, radius, color):
    radius = min(radius, w // 2, h // 2)
    fb.fill_rect(x + radius, y, w - radius * 2, h, color)
    fb.fill_rect(x, y + radius, w, h - radius * 2, color)
    fill_circle(x + radius, y + radius, radius, color)
    fill_circle(x + w - radius - 1, y + radius, radius, color)
    fill_circle(x + radius, y + h - radius - 1, radius, color)
    fill_circle(x + w - radius - 1, y + h - radius - 1, radius, color)


def draw_thick_line(x1, y1, x2, y2, color, thickness=2):
    half = thickness // 2
    for offset in range(-half, half + 1):
        fb.line(x1, y1 + offset, x2, y2 + offset, color)
        fb.line(x1 + offset, y1, x2 + offset, y2, color)


def draw_trend_arrow(cx, cy, trend, color=COLOR_TEXT):
    if trend > 0:
        draw_thick_line(cx, cy + 11, cx, cy - 11, color, 4)
        draw_thick_line(cx, cy - 11, cx - 8, cy - 3, color, 4)
        draw_thick_line(cx, cy - 11, cx + 8, cy - 3, color, 4)
    elif trend < 0:
        draw_thick_line(cx, cy - 11, cx, cy + 11, color, 4)
        draw_thick_line(cx, cy + 11, cx - 8, cy + 3, color, 4)
        draw_thick_line(cx, cy + 11, cx + 8, cy + 3, color, 4)
    else:
        draw_thick_line(cx - 11, cy, cx + 11, cy, color, 4)
        draw_thick_line(cx + 11, cy, cx + 3, cy - 8, color, 4)
        draw_thick_line(cx + 11, cy, cx + 3, cy + 8, color, 4)


def draw_compact_trend_arrow(cx, cy, trend, color=COLOR_TEXT):
    if trend > 0:
        draw_thick_line(cx, cy + 6, cx, cy - 6, color, 2)
        draw_thick_line(cx, cy - 6, cx - 4, cy - 2, color, 2)
        draw_thick_line(cx, cy - 6, cx + 4, cy - 2, color, 2)
    elif trend < 0:
        draw_thick_line(cx, cy - 6, cx, cy + 6, color, 2)
        draw_thick_line(cx, cy + 6, cx - 4, cy + 2, color, 2)
        draw_thick_line(cx, cy + 6, cx + 4, cy + 2, color, 2)
    else:
        draw_thick_line(cx - 6, cy, cx + 6, cy, color, 2)
        draw_thick_line(cx + 6, cy, cx + 2, cy - 4, color, 2)
        draw_thick_line(cx + 6, cy, cx + 2, cy + 4, color, 2)


def trend_label(trend):
    if trend > 0:
        return "RISING"
    if trend < 0:
        return "FALLING"
    return "STEADY"


def map_value(value, in_min, in_max, out_min, out_max):
    if value < in_min:
        value = in_min
    if value > in_max:
        value = in_max
    return out_min + (value - in_min) * (out_max - out_min) // (in_max - in_min)


def draw_ring(cx, cy, outer_radius, thickness, color, inner_color):
    fill_circle(cx, cy, outer_radius, color)
    fill_circle(cx, cy, outer_radius - thickness, inner_color)


def draw_circle_outline(cx, cy, radius, thickness, color):
    inner_radius = radius - thickness
    if inner_radius < 0:
        inner_radius = 0
    outer2 = radius * radius
    inner2 = inner_radius * inner_radius
    for yy in range(-radius, radius + 1):
        y = cy + yy
        outer_remaining = outer2 - yy * yy
        if outer_remaining < 0:
            continue
        outer_span = int(outer_remaining ** 0.5)
        inner_remaining = inner2 - yy * yy
        if inner_remaining < 0:
            fb.hline(cx - outer_span, y, outer_span * 2 + 1, color)
        else:
            inner_span = int(inner_remaining ** 0.5)
            width = outer_span - inner_span
            if width > 0:
                fb.hline(cx - outer_span, y, width, color)
                fb.hline(cx + inner_span + 1, y, width, color)


def draw_step_dots(step, total):
    if total <= 0:
        return
    spacing = 12
    radius = 3
    start_x = WIDTH - 16 - (total - 1) * spacing
    y = 14
    for index in range(total):
        color = COLOR_FOCUS if index < step else COLOR_EDGE
        fill_circle(start_x + index * spacing, y, radius, color)
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

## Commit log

2025-03-23 Upload initial pump code
    First version of the insulin pump code. Not yet fully complete.
2026-08-30 Document MK2 hardware and publish PCB V2 source
    [1e-knopje.kicad_sch, 2e-knopje.kicad_sch, 3e-knopje.kicad_sch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]
